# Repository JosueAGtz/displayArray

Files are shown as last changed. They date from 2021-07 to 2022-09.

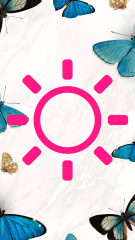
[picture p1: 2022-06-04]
Media/displayArray Plus Themes/ButterflyBig/brightness.png

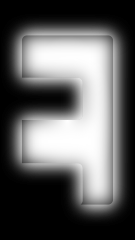
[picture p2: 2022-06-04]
Media/displayArray Plus Themes/StargateBig/am.png

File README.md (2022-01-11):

# Display Array Board
displayArray

The display array is a board that sets 6 ST7735 display with a resolution of 80x160px in a linear array sharing the clock, data, rs, backlight pins together, and leaving individual access to the cs lines of each display, The PCB is intended to be compatible with any Microcontroller or SBC like the Raspberry as it only needs some GPIOs and an SPI Port. This makes the PCB compatible with a simple microcontroller as an Arduino to other more advanced microcontrollers. We could say this board is a breakout board for the arrangement of six displays and 4 buttons. 

The display array has a back connector that allows the comunication with the displays and buttons. The pinout of the connector is the following:

displayArrayPinout

# Display Array Clock Themes ( MY TOP 5 )

displayArrayBINA

displayArrayFlip

displayArray14Seg

displayArrayVFD

displayArrayNixie

# Display Array Clock 

displayArrayClock

# Get the Display Array Board & Controller 

displayArraykofi (https://ko-fi.com/josuealejandrogtz)



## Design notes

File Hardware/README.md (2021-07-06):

# Display Array Hardware

With this files you should be able to modify the board as need, also you can fabricate your own board by using the Gerber files and BOM. 

### Printed Circuit Board
displayArrayPCB

### Schematic
displayArraySCH

### Display Array Board
displayArrayFront
displayArrayBack

# Display Array Controller Hardware

The controller board integrates an ESP32-S2 for its integrated USB Bootloader making it a very compact board with a powerful microcontroller with wifi and Bluetooth capabilities.

This board connects directly to the SPI Display Array Board in its back, it also has an RGB LED and Audio Amplifier for color and audible notifications. The hardware is more than capable to manage 6 displays at a decent frame rate and has enough memory for more than 5 different timezones and clock themes.

This controller has also take into account the possibility of an 8 display board and different display controller detection by the reading of one GPIO, Low logic state for ST7735, and High logic state for ST7789.

### Printed Circuit Board
displayArrayCtrlPCB

### Display Array Controller Board
displayArrayCtrl
displayArrayCtrlMount

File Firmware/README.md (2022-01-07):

## ESP32-S2 Pinout

displayArraySaola

### SPI and Buttons < main.h >
```c++

#define PIN_NUM_RST     33
#define PIN_NUM_DC      34
#define PIN_NUM_MOSI    35
#define PIN_NUM_CLK     36
#define PIN_NUM_BLK     37
#define PIN_NUM_MISO    -1

#define PIN_NUM_CS1     1
#define PIN_NUM_CS2     2
#define PIN_NUM_CS3     3
#define PIN_NUM_CS4     4
#define PIN_NUM_CS5     5
#define PIN_NUM_CS6     6
#define PIN_NUM_CS7     7
#define PIN_NUM_CS8     8

#define PIN_NUM_BTN     0
#define PIN_NUM_BTA     10
#define PIN_NUM_BTB     11
#define PIN_NUM_BTC     12 
#define PIN_NUM_BTD     13

```
## Raspberry Pi Pico Pinout

displayArrayPico

### SPI Port < ST7735.h>

```c++
#define PIN_BLK     21
#define PIN_RST     20
#define PIN_DC      19
#define PIN_SDI     18
#define PIN_SCK     17
#define PIN_CS      16
#define PIN_CS1      16
#define PIN_CS2      15
#define PIN_CS3      14
#define PIN_CS4      13
#define PIN_CS5      12
#define PIN_CS6      11
```

### Buttons < main.h >

```c++
#define PIN_BTNA      6
#define PIN_BTNB      7
#define PIN_BTNC      8
#define PIN_BTND      9
```

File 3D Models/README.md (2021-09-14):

# Display Array 3D Files

### Display Array
displayArray3D

### Controller Board
displayArrayCtrl3D

### USB Board
displayArray3DUSB

### Clock Case
displayArray3D

displayArray3D

### Clock 3D Printed Case
displayArray3DPrint

### Clock Resin 3D Printed Case
displayArray3DPrint
displayArray3DPrint
displayArray3DPrint
displayArray3DPrint

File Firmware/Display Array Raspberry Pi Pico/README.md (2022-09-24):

## Display Array Clock Firmware

For this clock project, I’m using a Raspberry Pi Pico, but the code should be easily ported to any other microcontroller, as the functionality of the clock itself is basic. The Raspberry Pi Pico has a built-in RTC so results easier to implement the clock. Other Microcontrollers with Wifi Capabilities could also obtain the clock data from a web service instead of an intrnal RTC making the board capabilities more atractive as weather or many other kind of IOT notificaions.

displayArrayPico

### SPI Port < ST7735.h>

```c++
#define PIN_BLK     21
#define PIN_RST     20
#define PIN_DC      19
#define PIN_SDI     18
#define PIN_SCK     17
#define PIN_CS      15
#define PIN_CS1      15
#define PIN_CS2      14
#define PIN_CS3      13
#define PIN_CS4      12
#define PIN_CS5      11
#define PIN_CS6      10
```

### Buttons < main.h >

```c++
#define PIN_BTNA      6
#define PIN_BTNB      7
#define PIN_BTNC      8
#define PIN_BTND      9
```

## Posible error in the Pico SDK
There is a chance that your pico-SDK has an error and the program would not start. In your SDK directory: pico-sdk/src/common/pico_time/time.c file comment line 17, //CU_SELECT_DEBUG_PINS(core) and now the program should run with any problem.

```c++
/*
 * Copyright (c) 2020 Raspberry Pi (Trading) Ltd.
 *
 * SPDX-License-Identifier: BSD-3-Clause
 */

#include <limits.h>
#include <stdio.h>
#include <stdlib.h>
#include "pico.h"
#include "pico/time.h"
#include "pico/util/pheap.h"
#include "hardware/sync.h"
#include "hardware/gpio.h"

CU_REGISTER_DEBUG_PINS(core)
//CU_SELECT_DEBUG_PINS(core)

const absolute_time_t ABSOLUTE_TIME_INITIALIZED_VAR(nil_time, 0);
// use LONG_MAX not ULONG_MAX so we don't have sign overflow in time diffs
const absolute_time_t ABSOLUTE_TIME_INITIALIZED_VAR(at_the_end_of_time, ULONG_MAX);

typedef struct alarm_pool_entry {
    absolute_time_t target;
    alarm_callback_t callback;
    void *user_data;
} alarm_pool_entry_t;
```

## Upload your UF2 to your Pico

To upload your code to your pico you just need to connect your pico USB to your computer while holding down the BOOTSEL button on your Pico, this will tell your pico to be mounted as an external drive on your computer where you can just copy paste your UF2 file.

displayArrayPicoUpload

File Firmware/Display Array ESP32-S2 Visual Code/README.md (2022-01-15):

## Visual Studio Code - Espressif Plugin ESP32-S2

The latest firmware includes the addition of 4 timezones with different clock themes with the corresponding country Flag, the firmware is based on the SNTP example provided by Expressif which allows you to configure and set your Wifi’s SSID and password for automatic clock time according to the chosen timezones.

I am very new with the ESP32 so I have tried with MicroPython, CircuitPython, Arduino, and Espressif repository running in Visual Studio Code, and the easiest for me was this last one, so I took the SNTP example located at the protocols example folder. In Visual Studio Code is the Espressif plug-in which makes it very easy and fast to get started with the ESP32.

displayArrayESP32

After installing and opening the example we just need to configure the example for the Wifi credentials and confirm that the partition table is set to 3M.

displayArrayConfig

displayArrayWifi

displayArrayPartition

If you are using the displayArray controller remmber that it does not have a USB to Serial converter so you will need to put it in Boodtloader mode by pressing reset and boot at the same time, then release the reset button and after 3 seconds release also the boot button and your controller will be in bootloader mode.

displayArrayCtlrBootMode

### ESP32-S2 Pinout

displayArraySaola

### SPI and Buttons < main.h >
```c++

#define PIN_NUM_RST     33
#define PIN_NUM_DC      34
#define PIN_NUM_MOSI    35
#define PIN_NUM_CLK     36
#define PIN_NUM_BLK     37
#define PIN_NUM_MISO    -1

#define PIN_NUM_CS1     1
#define PIN_NUM_CS2     2
#define PIN_NUM_CS3     3
#define PIN_NUM_CS4     4
#define PIN_NUM_CS5     5
#define PIN_NUM_CS6     6
#define PIN_NUM_CS7     7
#define PIN_NUM_CS8     8

#define PIN_NUM_BTN     0
#define PIN_NUM_BTA     10
#define PIN_NUM_BTB     11
#define PIN_NUM_BTC     12 
#define PIN_NUM_BTD     13

```

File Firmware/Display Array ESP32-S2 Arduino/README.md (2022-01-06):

# Configuring Arduino IDE for ESP32-S2
displayArray

In order to configure the Arduino IDE for the ESP32-S2 it is necessary to add the Espressif board configuration files.

1.- Open your arduino IDE Preferences and click the add Additional Boards Manager URLs

displayArrayArduinoPreferences

2.- Add the following Espressif Repository for ESP32-S2 URL:
```c++
https://raw.githubusercontent.com/espressif/arduino-esp32/gh-pages/package_esp32_dev_index.json
```
displayArrayArduinoURL

3.- Close and open again the Arduino IDE and click the menu Tools>Board>Boards Manager and search for ESP32 and install the latest version available. 

displayArrayArduinoBoardManager

4.- Now you can select the ESP32S2 Dev Module on the menu Tools>Board>ESP32 Arduino.

displayArrayArduinoBoardModule

For most of the displayArray apps you will need to use the Huge App partition scheme.

displayArrayArduinoBoardPartition

## Steps to install Arduino ESP32 support on Windows ( Alternative )
### Tested on 32 and 64 bit Windows 10 machines

1. Download and install the latest Arduino IDE ```Windows Installer``` from [arduino.cc](https://www.arduino.cc/en/Main/Software)
2. Download and install Git from [git-scm.com](https://git-scm.com/download/win)
3. Start ```Git GUI``` and run through the following steps:
    - Select ```Clone Existing Repository```

        Step 1

    - Select source and destination
        - Sketchbook Directory: Usually ```C:/Users/[YOUR_USER_NAME]/Documents/Arduino``` and is listed underneath the "Sketchbook location" in Arduino preferences.
        - Source Location: ```https://github.com/espressif/arduino-esp32.git```
        - Target Directory: ```[ARDUINO_SKETCHBOOK_DIR]/hardware/espressif/esp32```
        - Click ```Clone``` to start cloning the repository

            Step 2
            Step 3
    - open a `Git Bash` session pointing to ```[ARDUINO_SKETCHBOOK_DIR]/hardware/espressif/esp32``` and execute ```git submodule update --init --recursive``` 
    - Open ```[ARDUINO_SKETCHBOOK_DIR]/hardware/espressif/esp32/tools``` and double-click ```get.exe```

        Step 4

    - When ```get.exe``` finishes, you should see the following files in the directory

        Step 5

4. Plug your ESP32 board and wait for the drivers to install (or install manually any that might be required)
5. Start Arduino IDE
6. Select your board in ```Tools > Board``` menu
7. Select the COM port that the board is attached to
8. Compile and upload (You might need to hold the boot button while uploading)

    Arduino IDE Example

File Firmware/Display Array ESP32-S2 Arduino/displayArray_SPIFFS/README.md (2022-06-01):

# Display Array Clock using 3MB SPIFFS
displayArrayMenu

This code uses the ESP32-S2 Stick internal flash memory for the APP(1MB) and SPIFFS(3MB) making posible just to copy paste your PNG theme files directly to the data folder in your Arduino project and uploaded directly using the SPIFFS Uploader for the ESP32-S2.

In order to use the SPIFFS you should have the SPIFFS tool for ESP32-S2 installed, you can download the tool from: https://github.com/etherfi/arduino-esp32fs-plugin-esp32s2/releases and copy the folder in C:\\Program Files\Arduino\tools like the image below:

displayArray_SPIFFSTOOL

Now that you have installed the SPIFFS Tool you should see in your arduino IDE the option to upload your data to your ESP32-S2.

displayArray_SPIFFSTOOL

The files that you want to upload shoud be contained in a directory data next to your Arduino Sketch, and remember to select the proper partition table for the app and data, in this case 1MB for the APP and 3MB for the data.

displayArray_SPIFFSTOOL

This sketch uses the bb_spi_lcd, PNGdec and NTPClient libraries, so be sure to copy those folders in to your Arduino libraries folder.

displayArrayThemes

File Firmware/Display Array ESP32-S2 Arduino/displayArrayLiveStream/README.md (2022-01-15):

# Display Array Youtube Livestream Notifier Firmware

displayArrayLive

For this Youtube Notifier project, you will need to add some libraries to your Arduino IDE. 

```c++
 Adafruit Neopixel
 Youtube API
 Arduino JSON
 BB SPI LCD
 ```
 
 To add this libraries open your Arduino IDE and click in "Tools>Manage Libraries"

displayArrayYoutube_manageLib

Search and install each library as shown below.

displayArrayYoutube_manageLib_Neopixel

displayArrayYoutube_manageLib_YoutubeAPI

displayArrayYoutube_manageLib_ArduinoJSON

displayArrayYoutube_manageLib_BBSPILCD

After installing all the libraries you should now be able to compile the code, so prepare your ESP32-S2 to load the app, dont forget to use Huge app as partition scheme.

displayArrayYoutube_verified

If you are using the displayArray controller remmber that it does not have a USB to Serial converter so you will need to put it in Boodtloader mode by pressing reset and boot at the same time, then release the reset button and after 3 seconds release also the boot button and your controller will be in bootloader mode. 

displayArrayCtlrBootMode

Now press the upload button to load your app in to your ESP32-S2.

displayArrayYoutube_uploading

For the displayArray controller you will have this message at the end but dont worry your app has been loaded sucessfully and you just need to press the restart button on the controller board. 

displayArrayYoutube_uploadErr

Now its time to configure your desired Youtube Channels IDs and Wifi Credentials

displayArrayYoutube_Settings

displayArrayYoutube_YoutubersImages

The Youtubers Images should be converted and pasted in to the Youtubers.h file, I like to use LCD Image Converter for this.

displayArrayYoutube_YoutubersImagesHEX

## Troubleshooting

You might encounter a little problem with Youtube Livestream Arduino Library as me, this happens because the Youtube page is not always in english and that depends on your location, as I live in Mexico the youtube.com page is always in spanish and that it is why you might need to search for other word rather than "watching".

I have used the word " EN VIVO " -> "{\"text\":\"EN VIVO\"}". to get the livestream in the file YoutubeLiveStream.cpp file.

```c++
bool YouTubeLiveStream::scrapeIsChannelLive(const char *channelId, char *videoIdOut, int videoIdOutSize){
    char command[100];
    sprintf(command, youTubeChannelUrl, channelId);

    bool channelIsLive = true;

    #ifdef YOUTUBE_DEBUG
    Serial.print("url: ");
    Serial.println(command);
    #endif

    int statusCode = makeGetRequest(command, YOUTUBE_HOST, "*/*", YOUTUBE_ACCEPT_COOKIES_COOKIE);
    if(statusCode == 200) {
        if (!client->find("{\"text\":\"EN VIVO\"}"))  
        {
            #ifdef YOUTUBE_DEBUG
            Serial.println(F("Channel doesn't seem to be live"));
            #endif

            channelIsLive = false;
```
You can check what is the better word for you by opening the youtube.com page in an incognito window in your explorer and search in the code source.

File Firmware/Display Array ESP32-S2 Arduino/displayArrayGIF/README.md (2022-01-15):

# Display Array Animated GIF Firmware

displayArrayGIF_Animation

For this Animated GIF project, you will need to add some libraries to your Arduino IDE, this app was written by Larry Bank to test his awesome library capable of showing GIFs. 

```c++
 Animated GIF
 BB SPI LCD
 ```
 
 To add this libraries open your Arduino IDE and click in "Tools>Manage Libraries"

displayArrayGIF_manageLib

Search and install each library as shown below.

displayArrayGIF_manageLib_AnimatedGIF

displayArrayGIF_manageLib_BBSPILCD

After installing all the libraries you should now be able to compile the code, so prepare your ESP32-S2 to load the app, dont forget to use Huge app as partition scheme.

displayArrayGIF_verified

If you are using the displayArray controller remmber that it does not have a USB to Serial converter so you will need to put it in Boodtloader mode by pressing reset and boot at the same time, then release the reset button and after 3 seconds release also the boot button and your controller will be in bootloader mode. 

displayArrayCtlrBootMode

Now press the upload button to load your app in to your ESP32-S2.

displayArrayGIF_uploading

For the displayArray controller you will have this message at the end but dont worry your app has been loaded sucessfully and you just need to press the restart button on the controller board. 

displayArrayGIF_uploadErr

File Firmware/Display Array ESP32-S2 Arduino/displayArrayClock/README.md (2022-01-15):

# Display Array Clock Firmware

displayArrayClock

For this clock project, you will need to add some libraries to your Arduino IDE. 

```c++
 Adafruit Neopixel
 NTP Client
 BB SPI LCD
 ```
 
 To add this libraries open your Arduino IDE and click in "Tools>Manage Libraries"

displayArrayClock_manageLib

Search and install each library as shown below.

displayArrayClock_manageLib_Neopixel

displayArrayClock_manageLib_NTPClient

displayArrayClock_manageLib_BBSPILCD

After installing all the libraries you should now be able to compile the code, so prepare your ESP32-S2 to load the app, dont forget to use Huge app as partition scheme.

displayArrayClock_verified

If you are using the displayArray controller remmber that it does not have a USB to Serial converter so you will need to put it in Boodtloader mode by pressing reset and boot at the same time, then release the reset button and after 3 seconds release also the boot button and your controller will be in bootloader mode. 

displayArrayCtlrBootMode

Now press the upload button to load your app in to your ESP32-S2.

displayArrayClock_uploading

For the displayArray controller you will have this message at the end but dont worry your app has been loaded sucessfully and you just need to press the restart button on the controller board. 

displayArrayClock_uploadErr

Now its time to configure your clock as you prefer by selecting your favorite Clock Theme, your Flag and Timezone, I use the Find and replace option to change all the clock theme definitions and click Replace all.

displayArrayClock_Themerep

Set your Wifi Credentials

displayArrayClock_WifiCredentials

And for the time zone just set it in seconds, for example Mexico is GTM-6 that would be minus 6 hours so that will be -6 * 3600, as there are 3600 seconds in an hour. 

displayArrayClock_timezpnesetting

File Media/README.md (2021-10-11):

# Display Array Board Clock Themes

These are some themes that I have created to be use with the display array board. Every theme can be modified or resized with the Master SVG File for better results. 

### BINA View
displayArrayBINA
### Flip-Flap
displayArrayFlip
### 14 Segments
displayArray14Seg
### VFD
displayArrayVFD
### Nixie Tube
displayArrayNixie
### Pixie PRO
displayArrayPixie
### 7 Segments
displayArray7Seg
### Lixie Cyan
displayArrayLixieBlue
### Lixie Purple
displayArrayLixiePurple
### Matrix
displayArrayMatrix
### NIMO
displayArrayNIMO
### Notebook
displayArrayNotebook
### Wood
displayArrayWood
### Butterfly
displayArrayButterfly
### Flowers
displayArrayFlowers
### RGB
displayArrayRGB
### Predator
displayArrayPredator
### Stargate
displayArrayStargate

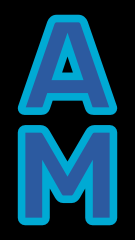
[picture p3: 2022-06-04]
Media/displayArray Plus Themes/SolidBlueBig/am.png

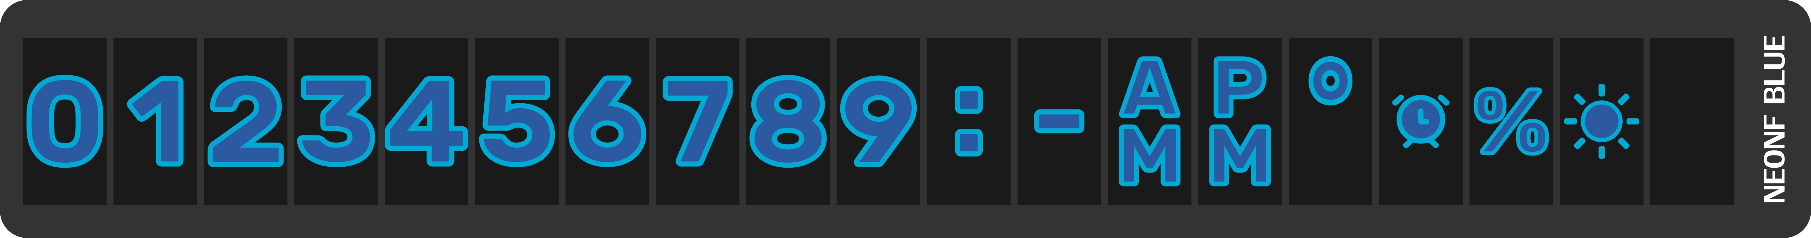
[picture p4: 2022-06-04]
Media/Clock Themes Preview/NeonfBlue.png

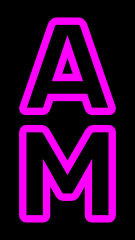
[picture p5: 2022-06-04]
Media/displayArray Plus Themes/NeonPurpleBig/am.png

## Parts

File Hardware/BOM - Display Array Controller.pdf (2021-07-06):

# BOM - SPI Display Array Controller

# | Reference | Part Number | Description | Manufacturer | Distribuitor | Quantity

1 | U1 | ESP32-S2-WROOM | Módulos WiFi (802.11) SMD module, ESP32-S2, 4 MB SPI flash, PCB antenna | Espressif | MOUSER | 1
2 | U2 | NCP187AMT330TAG | LDO Voltage Regulators 1.2A 3.3V Active discharge | On Semiconduxtor | MOUSER | 1
3 | U3 | PAM8301AAF | Audio Amplifiers Audio Amplifiers 1.5W MONO | Diodes Incorporated | MOUSER | 1
4 | S1,S2 | 434123025826 | Tactile Switches WS-TASV SMD 2.5mm 260g 50mA 16V White | WE | MOUSER | 2
5 | J1 | SSW-109-01-S-D | Board to Board & Mezzanine Connectors Tiger Buy Socket Strip with PCB Tails | SAMTEC | MOUSER | 1
6 | C2,C3,C4,C5,C7,C8 | 885012207098 | Multilayer Ceramic Capacitors MLCC - SMD/SMT WCAP-CSGP 0.1uF 0805 10% 50V MLCC | WE | MOUSER | 6
7 | C1,C6 | 885012207103 | Multilayer Ceramic Capacitors MLCC - SMD/SMT WCAP-CSGP 1uF 0805 10% 50V MLCC | WE | MOUSER | 2
8 | R1,R2 | ERJ-6GEYJ103V | Thick Film Resistors 0805 10Kohms 5% AEC-Q200 | Panasonic | MOUSER | 2
9 | D1 | SK6812 | RGB Serial LED | N/A | AliExpress | 1
10 | PCB | S/N | PCB Display Array Controller | N/A | N/A | 1

USB Data and Power Board

1 | J1 | S/N | 12 Pin Generic USBC Connector | N/A | Aliexpress | 1
2 | C1 | 885012207098 | Multilayer Ceramic Capacitors MLCC - SMD/SMT WCAP-CSGP 0.1uF 0805 10% 50V MLCC | WE | MOUSER | 1
3 | C2 | 885012207103 | Multilayer Ceramic Capacitors MLCC - SMD/SMT WCAP-CSGP 1uF 0805 10% 50V MLCC | WE | MOUSER | 1
4 | R1,R2 | ERJ-6GEYJ512V | Thick Film Resistors 0805 5.1Kohms 5% AEC-Q200 | Panasonic | MOUSER | 2
5 | L1 | BLM18KG221SN1D | Ferrite Beads 0603 220ohms 2.2A | Murata | MOUSER | 1
6 | F1 | 0ZCK0075FF2E | Resettable Fuses - PPTC | Bel Fuse | MOUSER | 1
7 | PCB | S/N | PCB USBC Data and Power | N/A | N/A | 1

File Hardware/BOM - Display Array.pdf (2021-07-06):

# BOM - SPI Display Array

# | Reference | Part Number | Description | Manufacturer | Distribuitor | Quantity

1 | Q1 | BSS316NH6327XTSA1 | MOSFET N-Ch 30V 1.4A SOT-23-3 | Infineon | MOUSER | 1
2 | S1,S2,S3,S4 | 434123025826 | Interruptores táctiles WS-TASV SMD 2.5mm 260g 50mA 16V White | WE | MOUSER | 1
3 | J1 | TSM-109-01-F-DH-A | Alojamientos de cables y cabecera .100" Surface Mount Terminal Strip | SAMTEC | MOUSER | 1
4 | C1,C2 | 885012207098 | Capacitores cerámicos (MLCC) - SMD/SMT WCAP-CSGP 0.1uF 0805 10% 50V MLCC | WE | MOUSER | 2
5 | R1,R2,R3,R4,R5 | ERJ-6GEYJ103V | Thick Film Resistors 0805 10Kohms 5% AEC-Q200 | Panasonic | MOUSER | 5
6 | DISPLAY1...6 | LH096NT-IG11G | 160x80 IPS Display Solder 0.96 inch 13 Pin | Limito | AliExpress | 6
7 | PCB | S/N | PCB Display Array | N/A | N/A | 1

Optional

8 | Cable connector | HCSD-09-S-12.00-01-N | IDC Cable 18 Pin | SAMTEC | N/A | 1

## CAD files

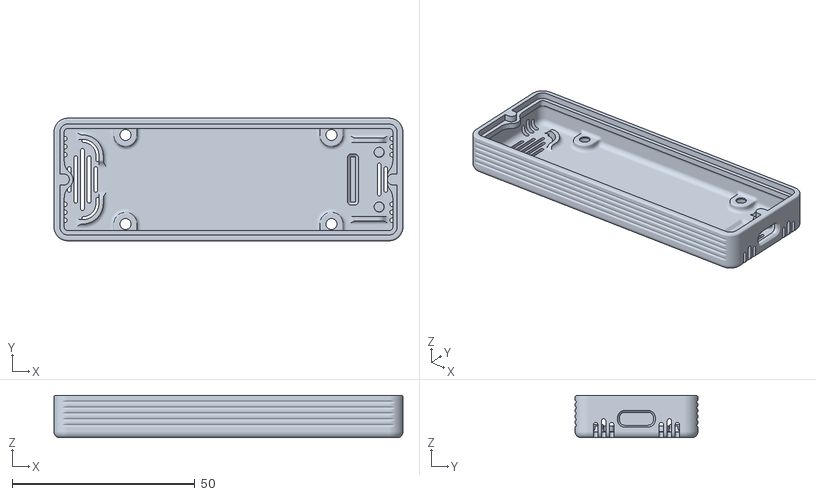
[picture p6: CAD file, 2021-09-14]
3D Models/ResinCase.stl
95.6 x 33.6 x 11.6

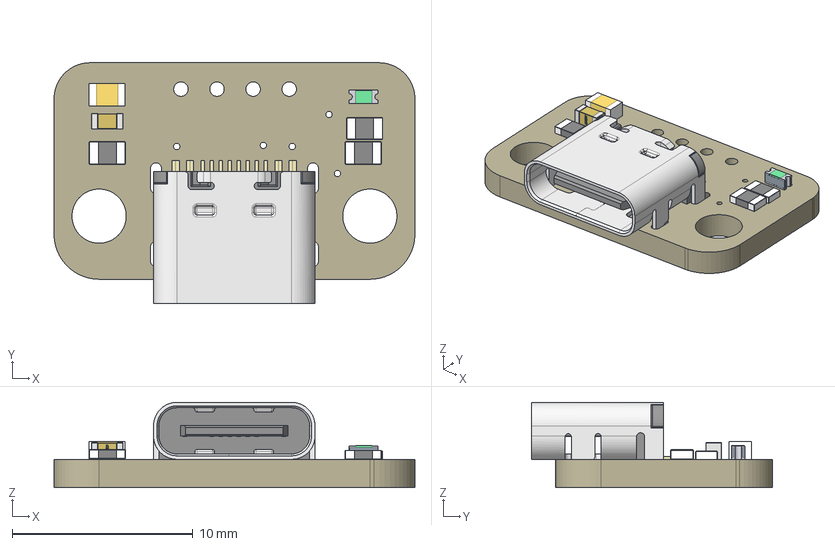
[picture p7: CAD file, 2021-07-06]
3D Models/ClockUSBSTP.step
20.0 x 13.3 x 4.73 mm
Board
C0603
C0603 (1)
core
core (1)
R0603 (2)
Lötende x 2
SE_SMALL_FACESILK
ConPins
PcbPins
Mold
Frame

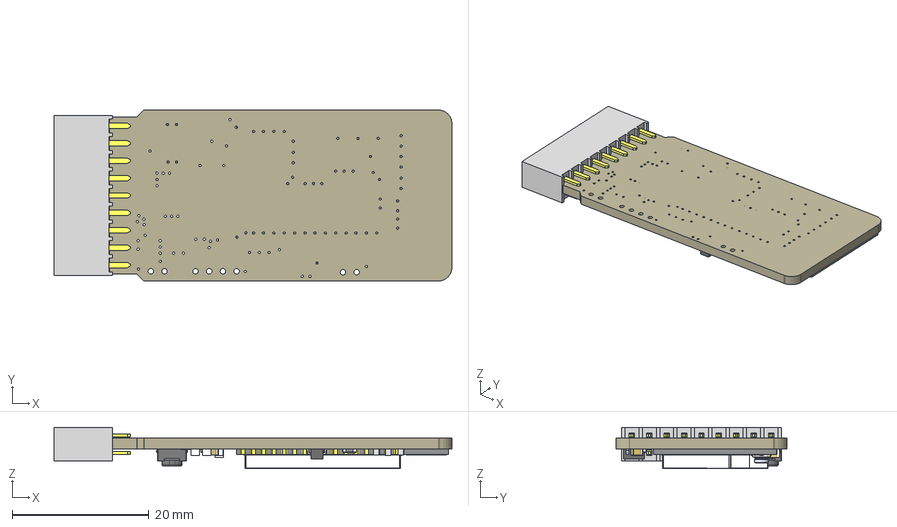
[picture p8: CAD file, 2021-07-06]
3D Models/ClockCtrlSTP.step
58.1 x 25.0 x 6.06 mm
Board
C0603
C0603 (1)
C0603 (2)
C0603 (3)
C0603 (4)
C0603 (5)
C0603 (6)
C0805
core
core (1)
XCVR_ESP32-S2-WROOM
_T1SSW-109-01-T-D
_P2SSW-109-01-T-D
Frame
Cover
Stem
Terminal x 4
Frame (1)
Cover (1)
Stem (1)
Terminal (1) x 4
SOT95P280X145-6N
SE_SMALL_FACESILK
SE_SMALL_SILK
20X20
SON65P250X250X80-7N

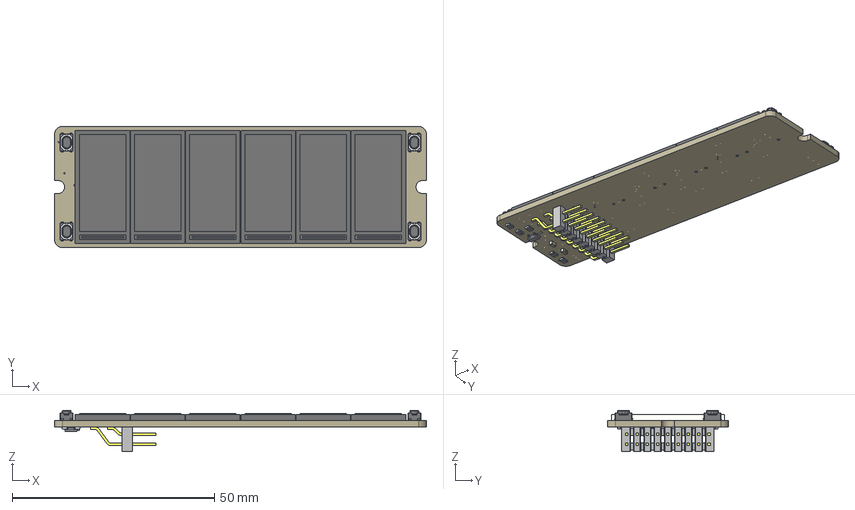
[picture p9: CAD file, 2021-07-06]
3D Models/DisplayArrayBoardSTP.step
92.0 x 30.0 x 10.2 mm
Board
SE_SMALL_SILK
_TSM-109-01-DH_body
_T-1S6-09(-01-9-DH)
C0603
C0603 (1)
core
core (1)
core (2)
core (3)
core (4)
SOT23
Frame
Cover
Stem
Terminal x 4
Frame (1)
Cover (1)
Stem (1)
Terminal (1) x 4
Frame (2)
Cover (2)
Stem (2)
Terminal (2) x 4
Frame (3)
Cover (3)
Stem (3)
Terminal (3) x 4
IPSLCD096_SOLDER
IPSLCD096_SOLDER (1)
IPSLCD096_SOLDER (2)
IPSLCD096_SOLDER (3)
IPSLCD096_SOLDER (4)
IPSLCD096_SOLDER (5)

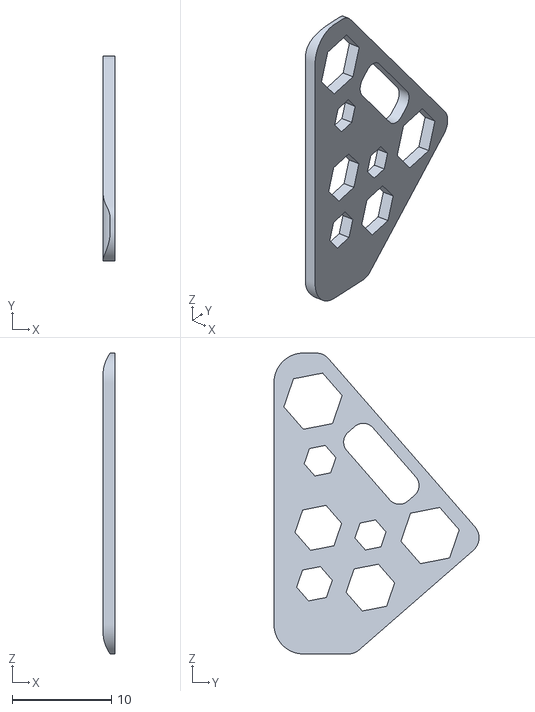
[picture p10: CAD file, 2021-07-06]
3D Models/USBSide.stl
1.20 x 20.7 x 30.4

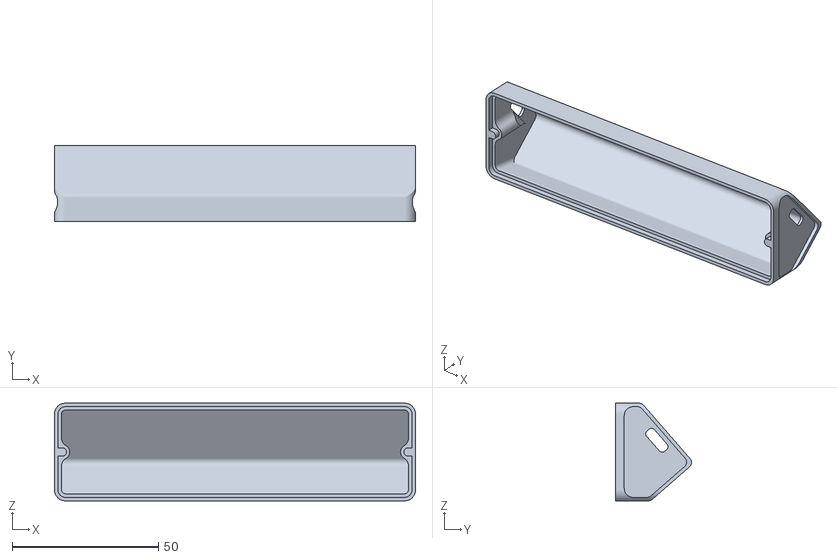
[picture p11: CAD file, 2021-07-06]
3D Models/8DisplayCaseSideUSB.stl
123.4 x 26.0 x 33.4

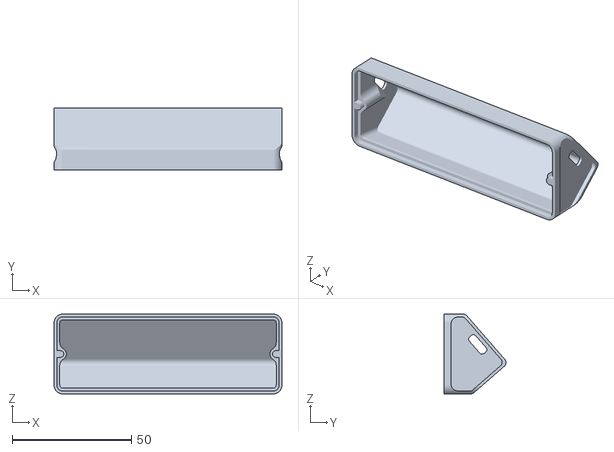
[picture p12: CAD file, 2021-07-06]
3D Models/6DisplayCaseSideUSB.stl
95.4 x 26.0 x 33.4

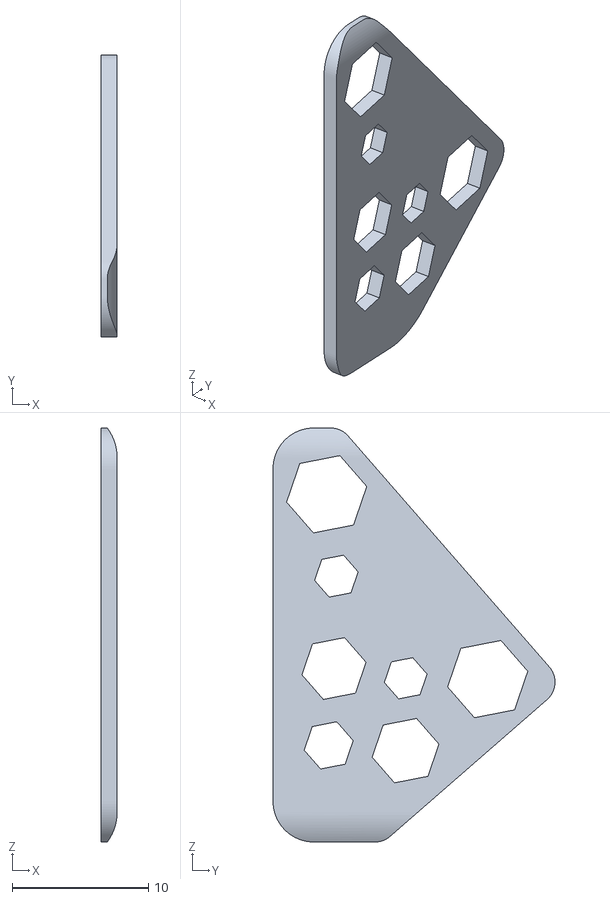
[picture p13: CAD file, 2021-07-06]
3D Models/BlindSide.stl
1.20 x 20.7 x 30.4

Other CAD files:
3D Models/6DisplayCaseBackUSB.stl
3D Models/8DisplayCaseBackUSB.stl

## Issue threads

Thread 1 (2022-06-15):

Crash when running "displayArrayClock"

ewecan, 2022-06-15:
Crashes after running for a few minutes

JosueAGtz, 2022-06-15:
Thanks for taking the time to report this issue, could you please indicate what code are you using or how is it crashing.
I have seen in the past the displayArray Clock app crashing when using the library manager to download or update the bb_spi_lcd, you could try using the included version provided here.

ewecan, 2022-06-17:
Thank you for your reply! Run "displayArrayClock.ino" in the ARDUINO folder, and after a few minutes, switching "space_Pixie" to "slash_Pixie" will get stuck

ewecan, 2022-06-17:
I tried to comment out the following code, the program can run for a long time, but it will still get stuck
 ```
 if((secondsCounter > 25) & (secondsStatus == 0)){
            lcdDrawNumber(2,10);
            //lcdDrawNumber(6,10);
            secondsStatus = 1;
            secondsCounter = 0;
        } else if((secondsCounter > 25) & (secondsStatus == 1)){
            lcdDrawNumber(2,11);
            //lcdDrawNumber(6,11);
            secondsStatus = 0;
            secondsCounter = 0;
        }
```

JosueAGtz, 2022-06-29:
Hi, I have now corrected those errors and the program should run normally, please copy the bb_spi_lcd folder into your Arduino libraries ( replace the existing version with the provided one).

Closed 2022-08-18.

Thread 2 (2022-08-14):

Firmware displayArray_SPIFFS may not work with clock ctrl board

shawnchain, 2022-08-14:
Hi,

Thanks for the great project!

I tested with the latest ClockCtrl eagle file and found the displayArray_SPIFFS may not work on it.
Possible issues include: Pin define mismatch, PWM not working, and SPI LCD write hang.

JosueAGtz, 2022-08-18:
Do you have the Espressif module controller version? I will add the pin definitions for the boards in the README file.

shawnchain, 2022-08-26:
ESP32-S2-4M

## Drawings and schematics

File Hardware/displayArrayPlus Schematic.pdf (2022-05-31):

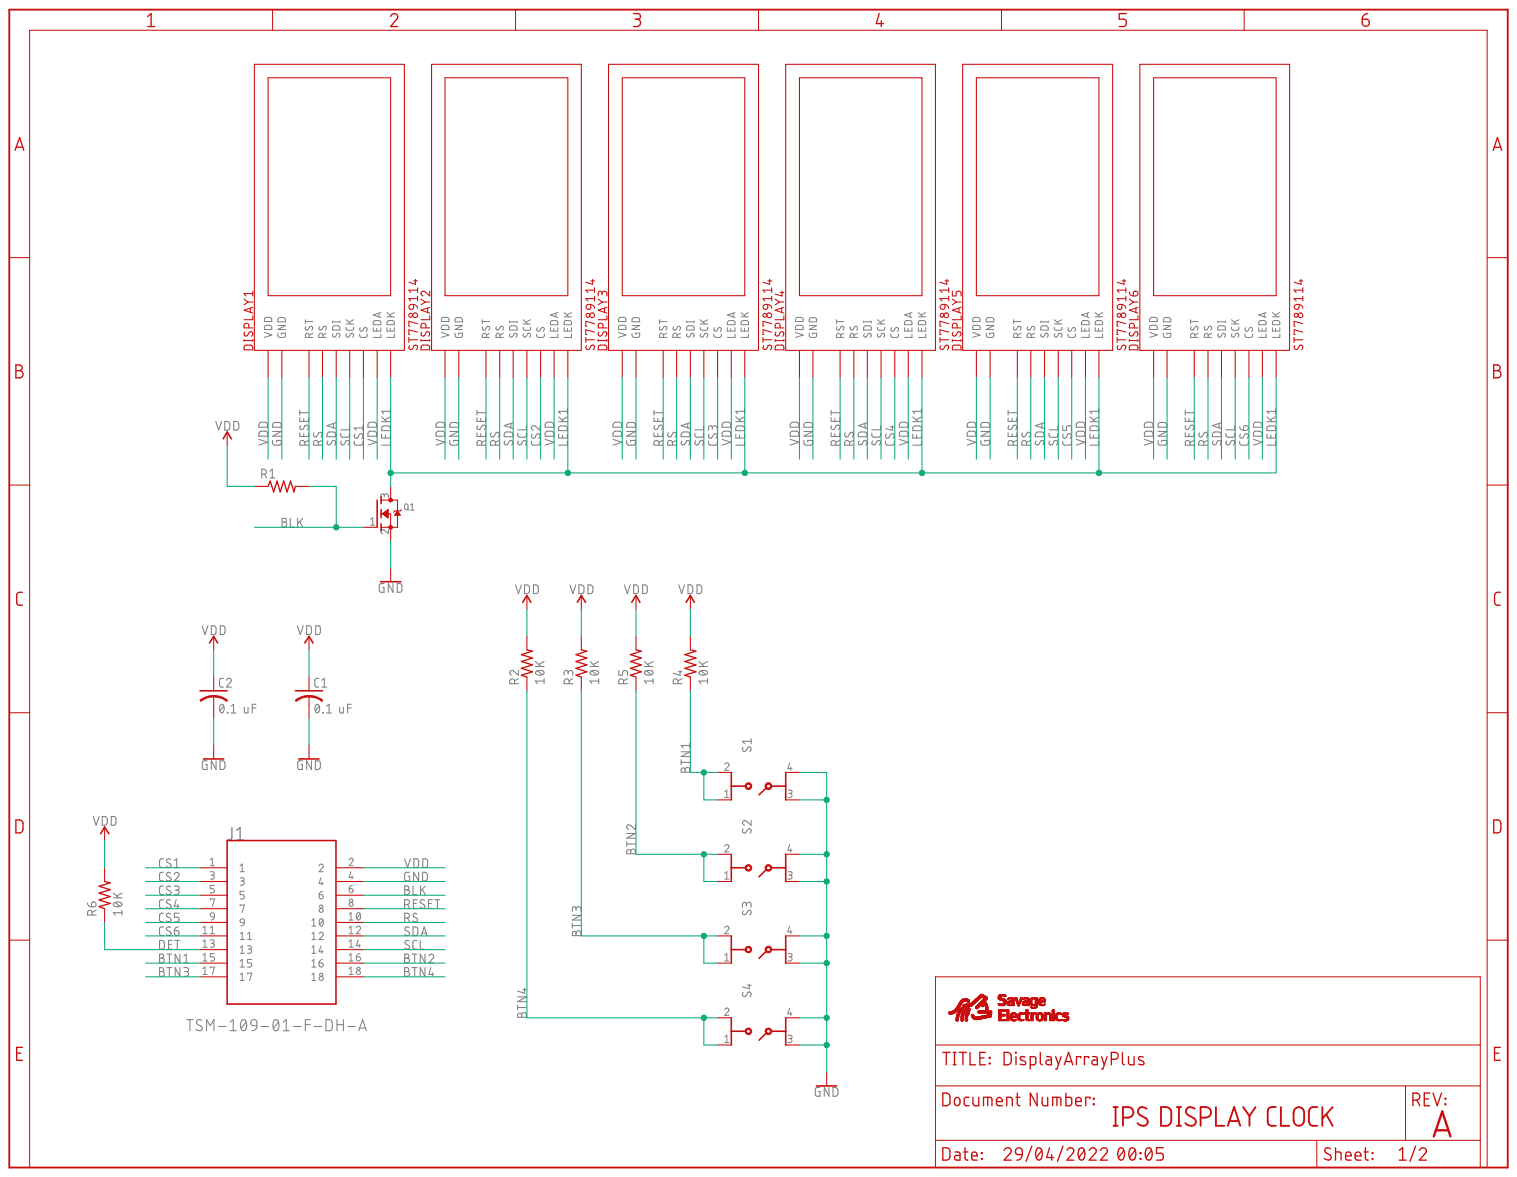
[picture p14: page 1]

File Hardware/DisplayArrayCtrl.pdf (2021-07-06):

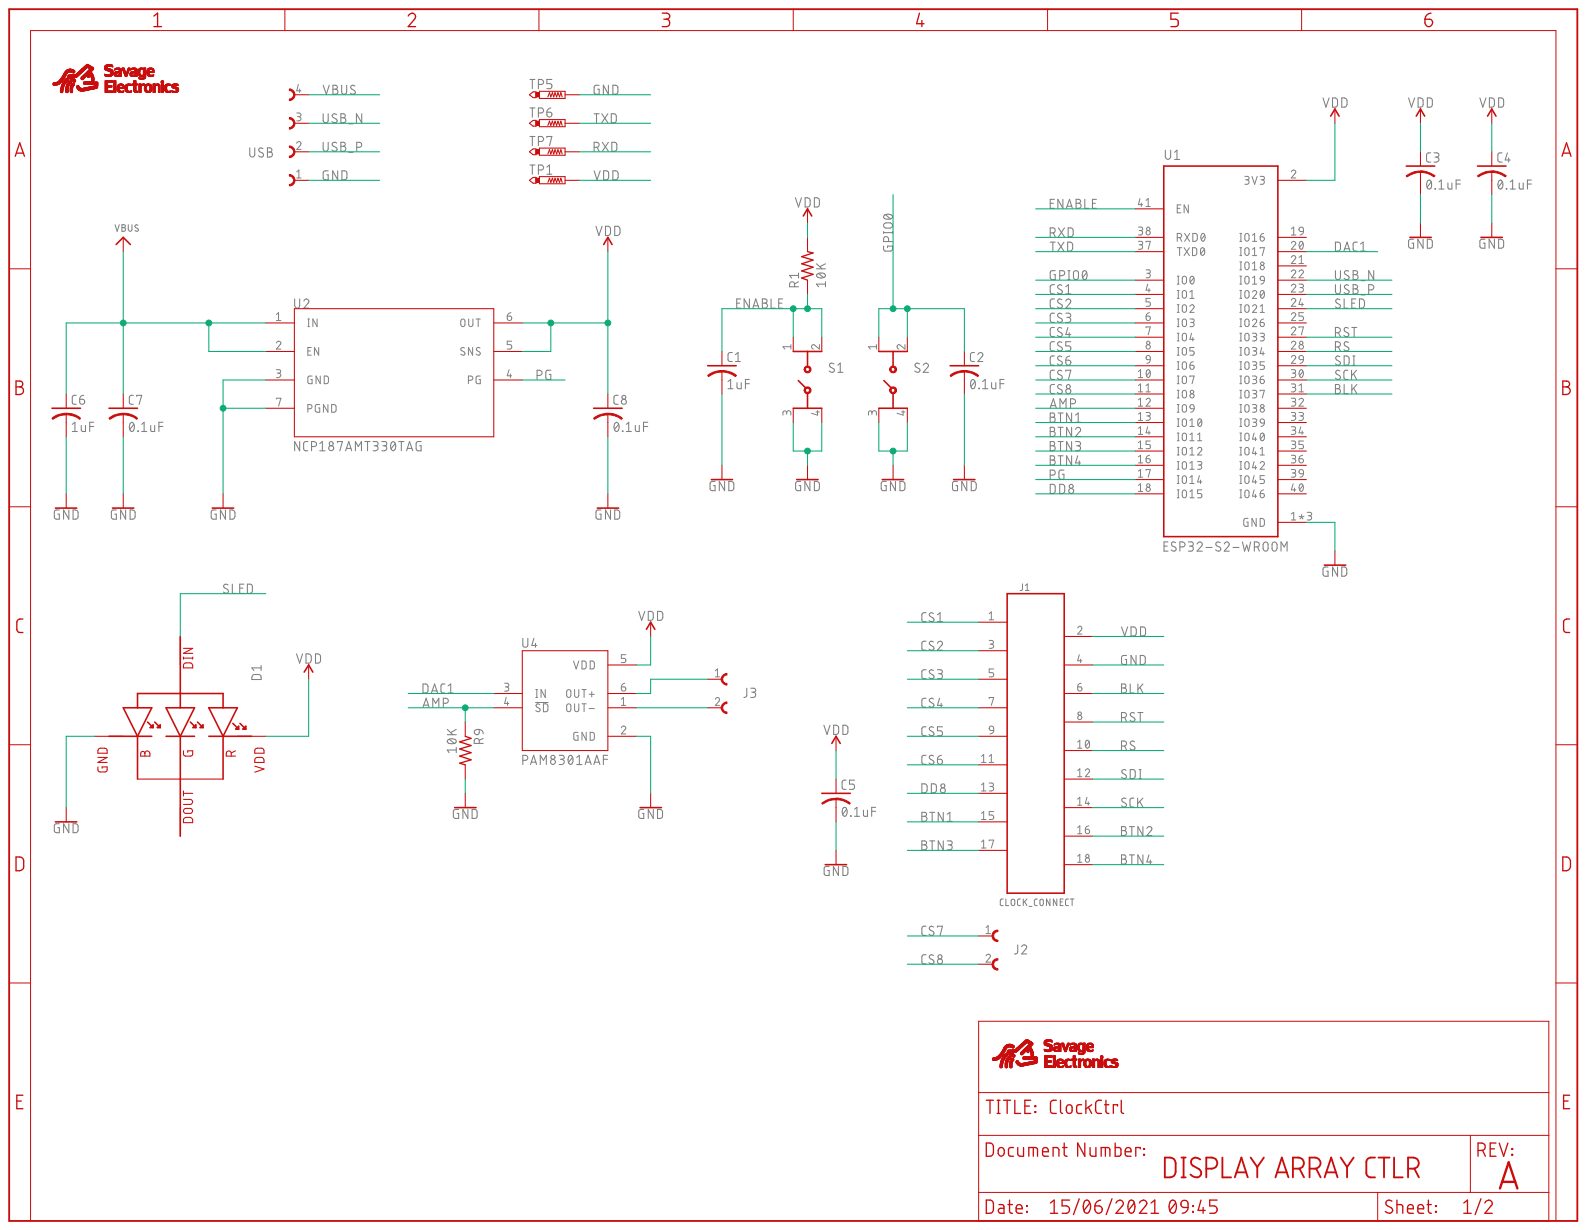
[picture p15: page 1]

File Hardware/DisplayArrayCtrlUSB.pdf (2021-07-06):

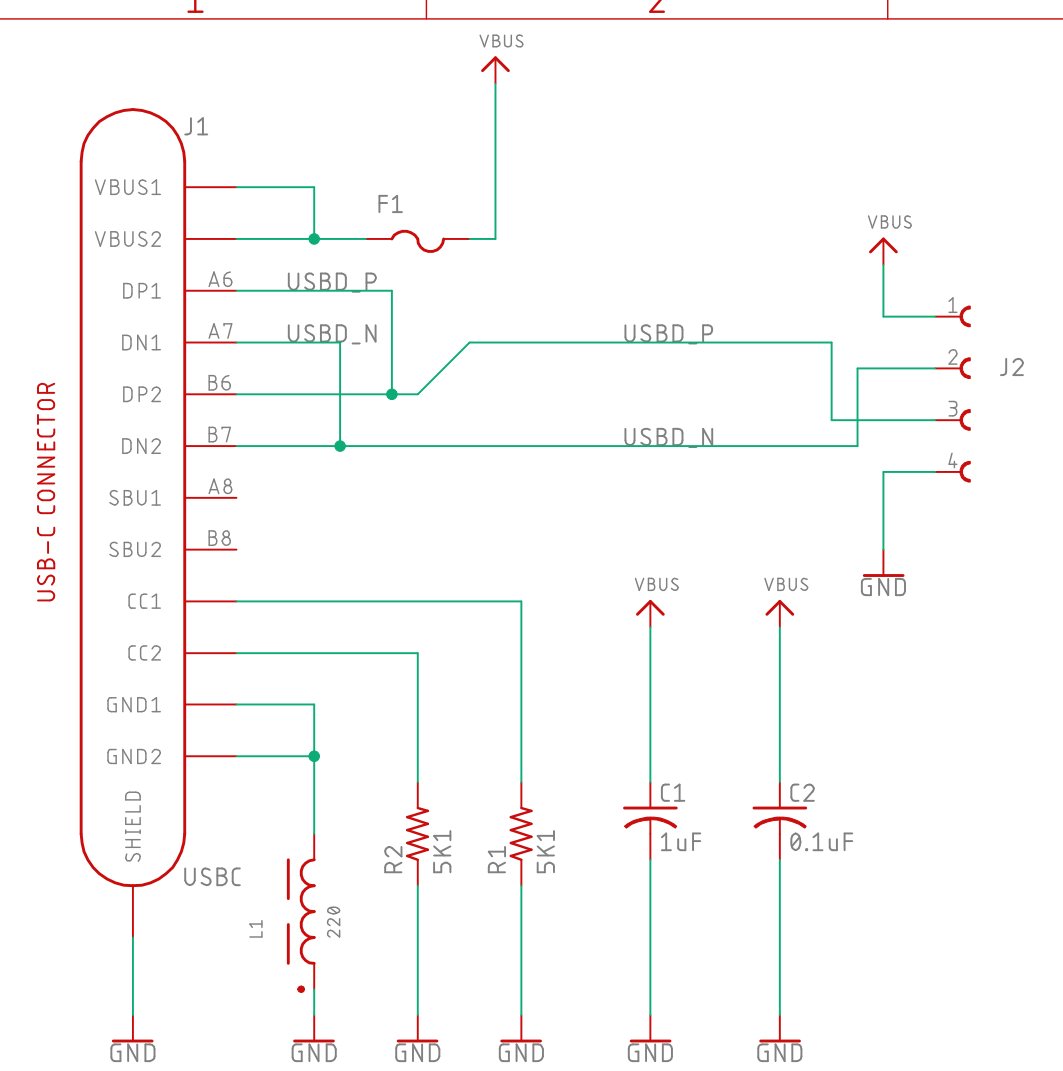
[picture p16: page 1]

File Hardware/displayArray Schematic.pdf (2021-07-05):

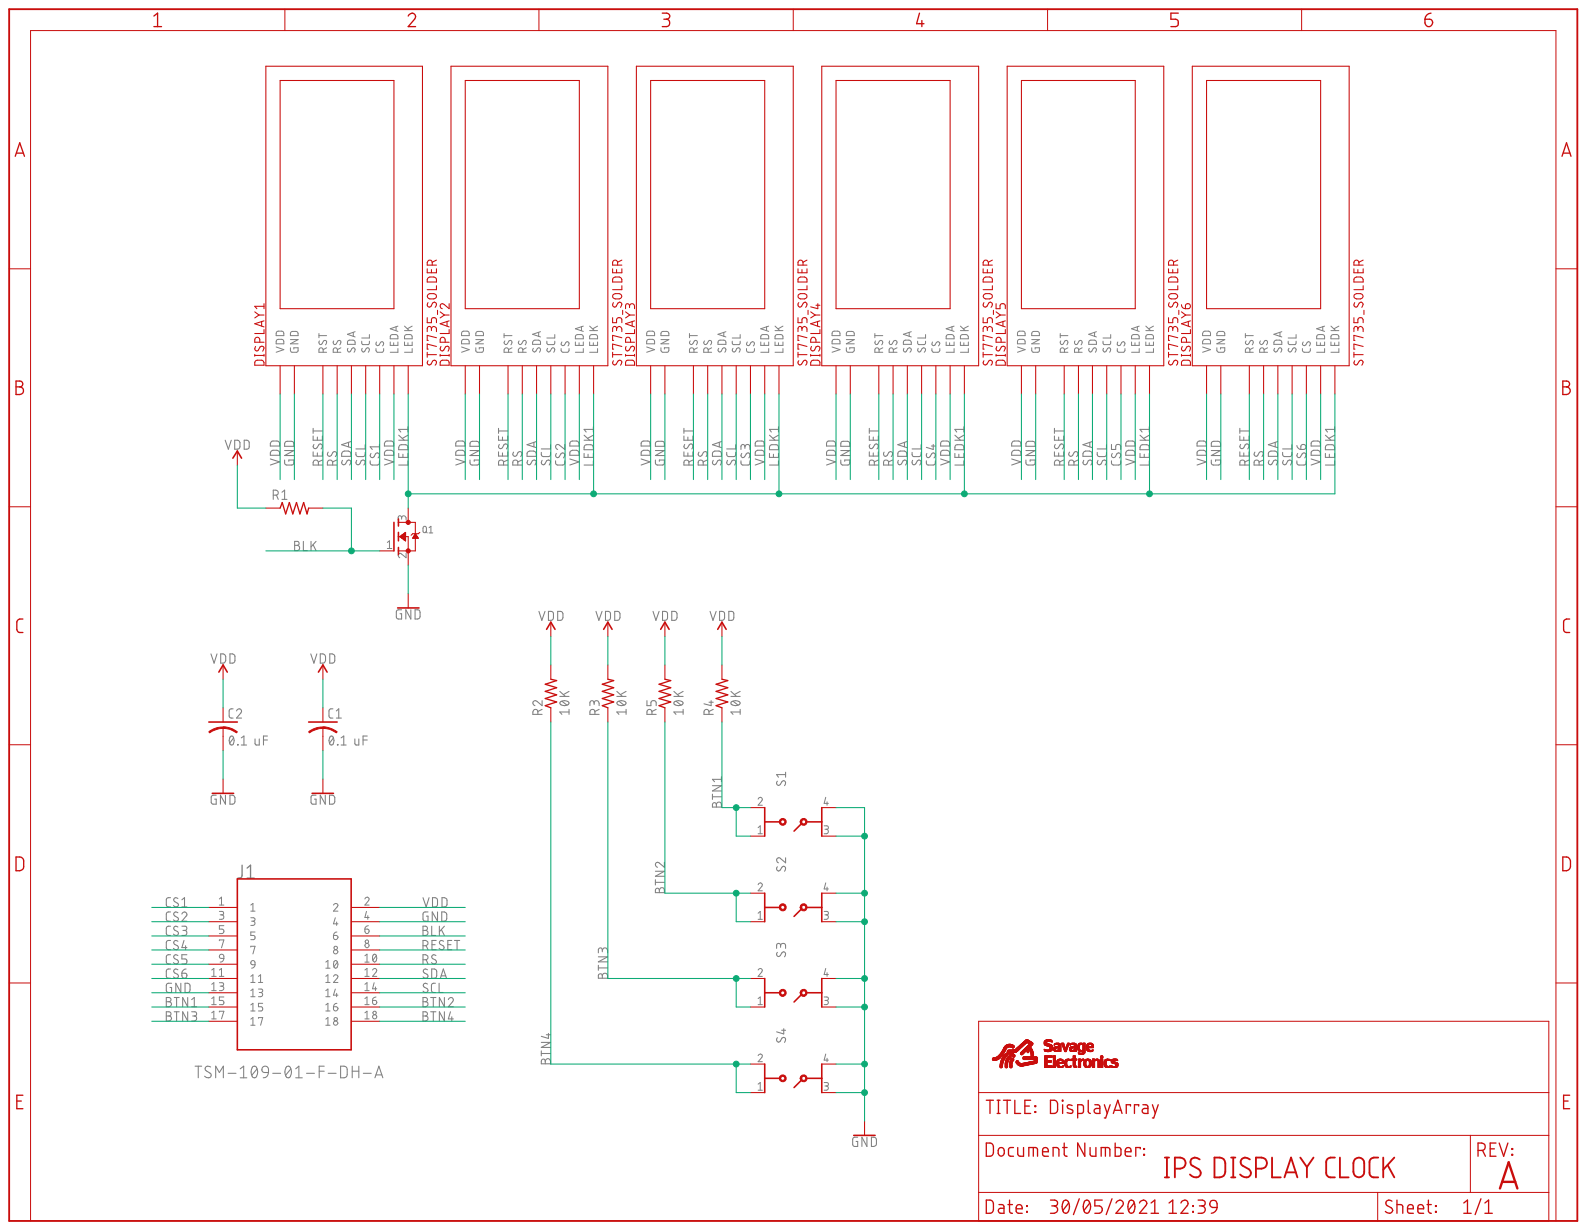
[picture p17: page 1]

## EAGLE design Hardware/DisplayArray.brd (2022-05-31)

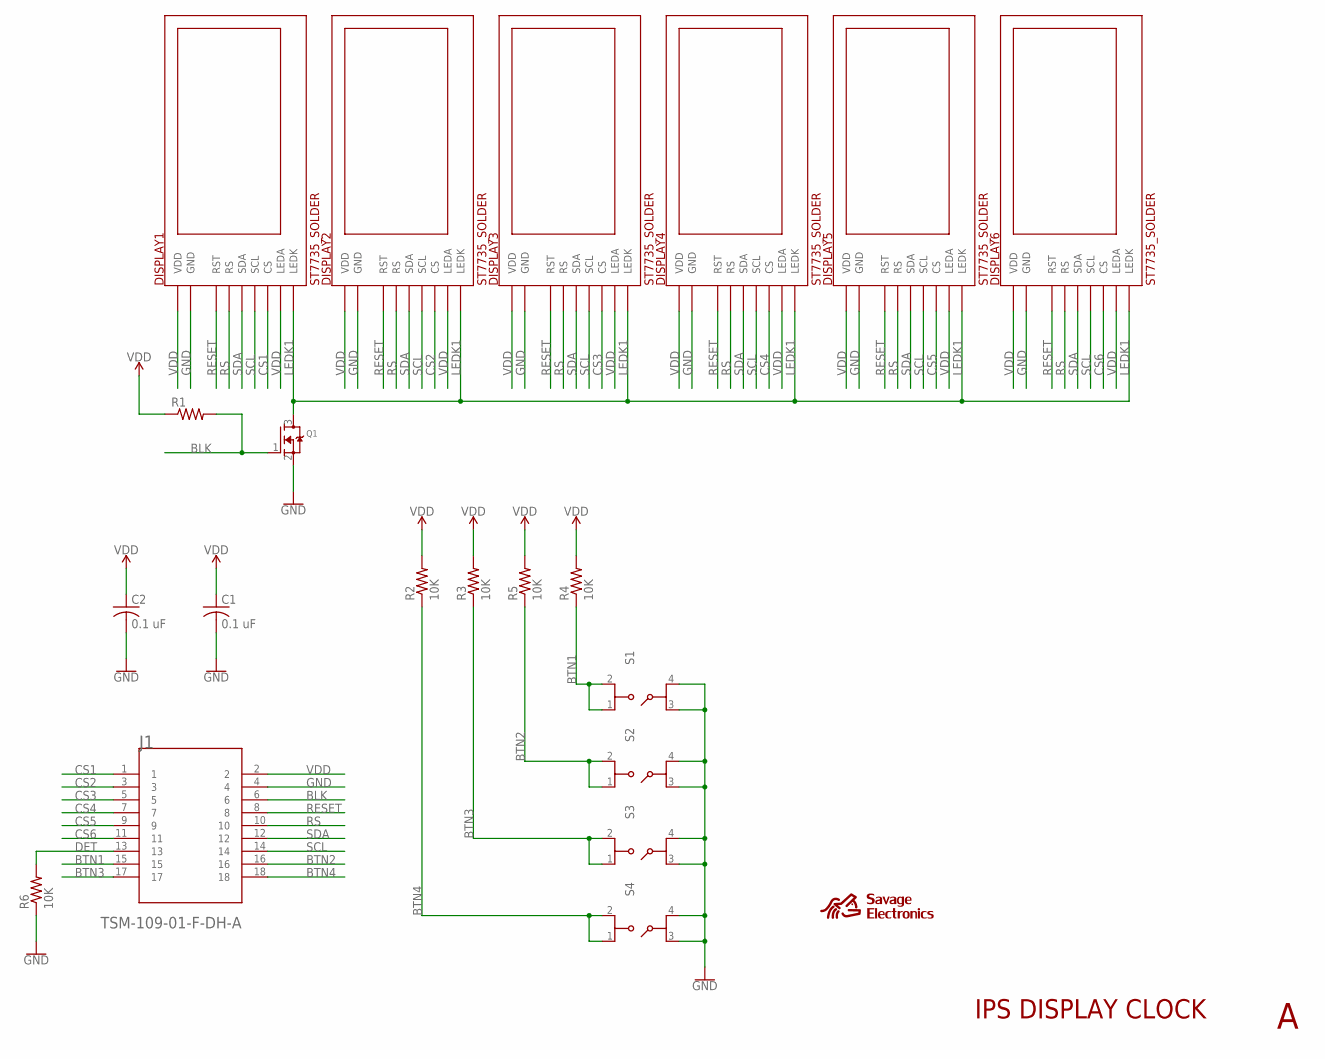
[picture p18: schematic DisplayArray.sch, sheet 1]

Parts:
C1, C2: 0.1 uF; C0603
DISPLAY1, DISPLAY2, DISPLAY3, DISPLAY4, DISPLAY5, DISPLAY6: ST7735_SOLDER; IPSLCD096_SOLDER
J1: TSM-109-01-F-DH-A; SAMTEC-TSM-109-02-X-DH-A
Q1: MOSFET-NREFLOW; SOT23
R1: R-US_R0805; R0805
R2, R3, R4, R5, R6: 10K; R0805
S1, S2, S3, S4: 434123025826
U$3: SE_SMALL_SILK

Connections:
BLK: J1.6, Q1.1 (G), R1.2
BTN1: J1.15, R4.1, S1.1, S1.2
BTN2: J1.16, R5.1, S2.1, S2.2
BTN3: J1.17, R3.1, S3.1, S3.2
BTN4: J1.18, R2.1, S4.1, S4.2
CS1: DISPLAY1.7 (CS), J1.1
CS2: DISPLAY2.7 (CS), J1.3
CS3: DISPLAY3.7 (CS), J1.5
CS4: DISPLAY4.7 (CS), J1.7
CS5: DISPLAY5.7 (CS), J1.9
CS6: DISPLAY6.7 (CS), J1.11
DET: J1.13, R6.2
GND: C1.2, C2.2, DISPLAY1.8 (GND), DISPLAY1.13 (GND), DISPLAY2.8 (GND), DISPLAY2.13 (GND), DISPLAY3.8 (GND), DISPLAY3.13 (GND), DISPLAY4.8 (GND), DISPLAY4.13 (GND), DISPLAY5.8 (GND), DISPLAY5.13 (GND), DISPLAY6.8 (GND), DISPLAY6.13 (GND), J1.4, Q1.2 (S), R6.1, S1.3, S1.4, S2.3, S2.4, S3.3, S3.4, S4.3, S4.4
LEDK1: DISPLAY1.11 (LEDK), DISPLAY2.11 (LEDK), DISPLAY3.11 (LEDK), DISPLAY4.11 (LEDK), DISPLAY5.11 (LEDK), DISPLAY6.11 (LEDK), Q1.3 (D)
RESET: DISPLAY1.6 (RST), DISPLAY2.6 (RST), DISPLAY3.6 (RST), DISPLAY4.6 (RST), DISPLAY5.6 (RST), DISPLAY6.6 (RST), J1.8
RS: DISPLAY1.5 (RS), DISPLAY2.5 (RS), DISPLAY3.5 (RS), DISPLAY4.5 (RS), DISPLAY5.5 (RS), DISPLAY6.5 (RS), J1.10
SCL: DISPLAY1.4 (SCL), DISPLAY2.4 (SCL), DISPLAY3.4 (SCL), DISPLAY4.4 (SCL), DISPLAY5.4 (SCL), DISPLAY6.4 (SCL), J1.14
SDA: DISPLAY1.3 (SDA), DISPLAY2.3 (SDA), DISPLAY3.3 (SDA), DISPLAY4.3 (SDA), DISPLAY5.3 (SDA), DISPLAY6.3 (SDA), J1.12
VDD: C1.1, C2.1, DISPLAY1.10 (VDD), DISPLAY1.12 (LEDA), DISPLAY2.10 (VDD), DISPLAY2.12 (LEDA), DISPLAY3.10 (VDD), DISPLAY3.12 (LEDA), DISPLAY4.10 (VDD), DISPLAY4.12 (LEDA), DISPLAY5.10 (VDD), DISPLAY5.12 (LEDA), DISPLAY6.10 (VDD), DISPLAY6.12 (LEDA), J1.2, R1.1, R2.2, R3.2, R4.2, R5.2

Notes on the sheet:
IPS DISPLAY CLOCK

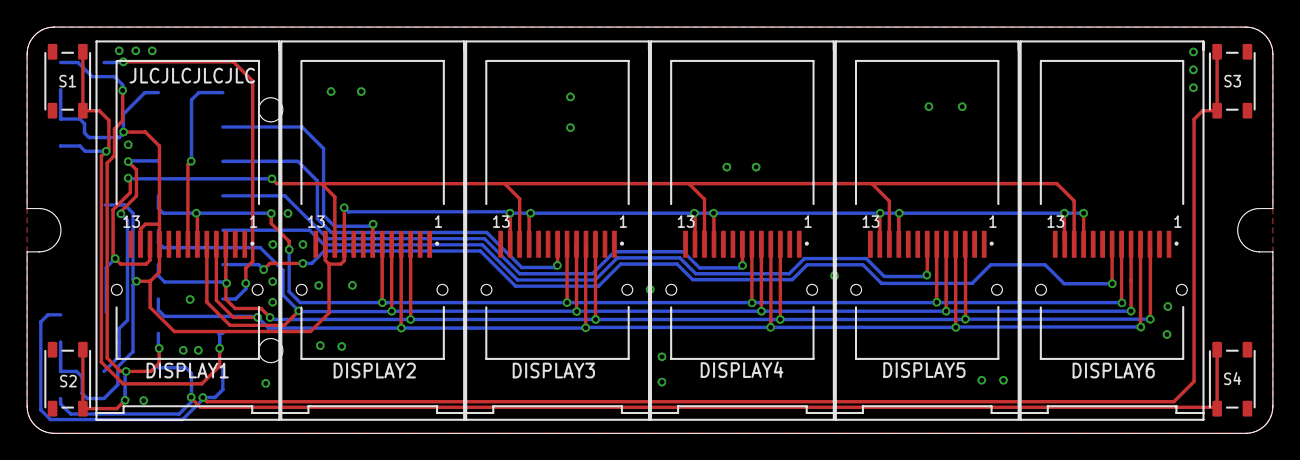
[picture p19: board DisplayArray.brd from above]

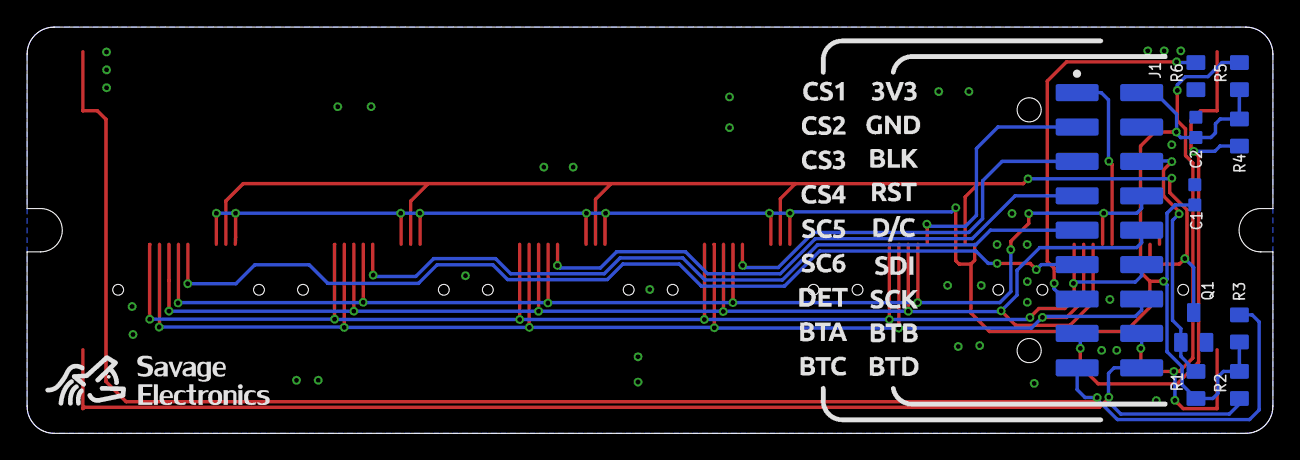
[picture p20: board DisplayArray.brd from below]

Board: 2 copper layers, 92.0 x 30.0 mm, 21 parts (11 on the bottom side), 19 nets.

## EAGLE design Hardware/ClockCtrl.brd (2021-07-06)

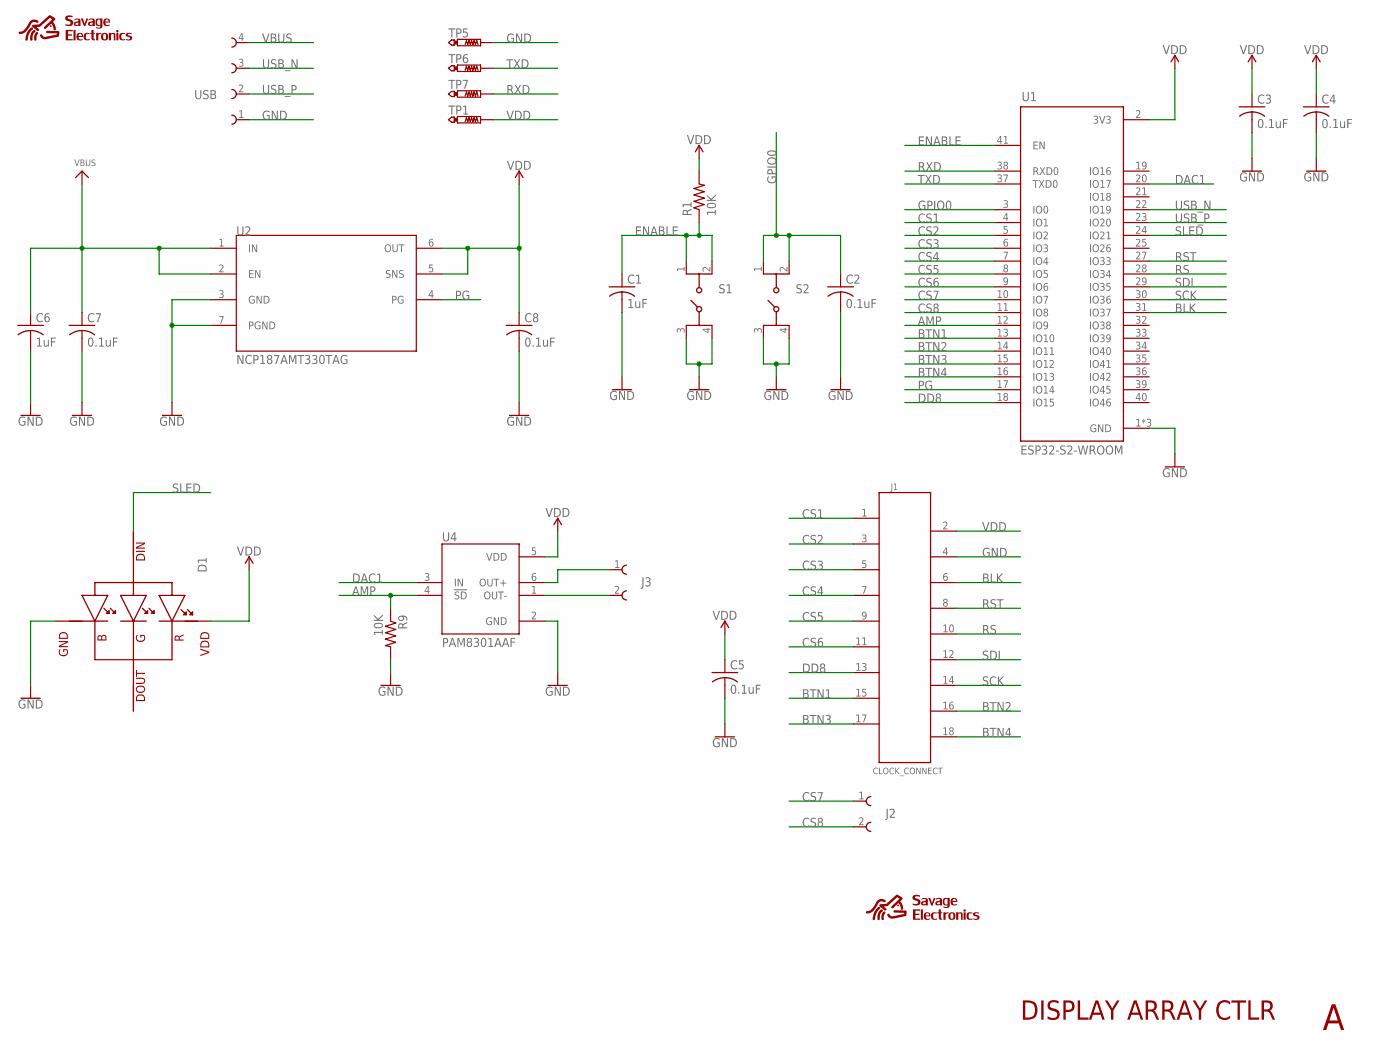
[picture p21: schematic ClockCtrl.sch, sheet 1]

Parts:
C1: 1uF; C0805
C2, C3, C4, C5, C7, C8: 0.1uF; C0603
C6: 1uF; C0603
D1: SK6812; 20X20
J1: CLOCK_CONNECT; CLOCKC_FOOTPRINT
J2, J3: 62000211121
R1, R9: 10K; R0603
S1, S2: 434123025826
TP1, TP5, TP6, TP7: PTR1TP12R; TP12R
U1: ESP32-S2-WROOM; XCVR_ESP32-S2-WROOM
U2: NCP187AMT330TAG; SON65P250X250X80-7N
U4: PAM8301AAF; SOT95P280X145-6N
U$1: SE_SMALL_FSILK; SE_SMALL_FACESILK
U$3: SE_SMALL_SILK
USB: 62000411121

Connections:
AMP: R9.1, U1.12 (IO9), U4.4 (!SD)
BLK: J1.6, U1.31 (IO37)
BTN1: J1.15, U1.13 (IO10)
BTN2: J1.16, U1.14 (IO11)
BTN3: J1.17, U1.15 (IO12)
BTN4: J1.18, U1.16 (IO13)
CS1: J1.1, U1.4 (IO1)
CS2: J1.3, U1.5 (IO2)
CS3: J1.5, U1.6 (IO3)
CS4: J1.7, U1.7 (IO4)
CS5: J1.9, U1.8 (IO5)
CS6: J1.11, U1.9 (IO6)
CS7: J2.1, U1.10 (IO7)
CS8: J2.2, U1.11 (IO8)
DAC1: U1.20 (IO17), U4.3 (IN)
DD8: J1.13, U1.18 (IO15)
ENABLE: C1.1, R1.1, S1.1, S1.2, U1.41 (EN)
GND: C1.2, C2.2, C3.2, C4.2, C5.2, C6.2, C7.2, C8.2, D1.3 (GND), J1.4, R9.2, S1.3, S1.4, S2.3, S2.4, TP5.TP, U1.1 (GND), U1.26 (GND), U1.42 (GND), U2.3 (GND), U2.7 (PGND), U4.2 (GND), USB.1
GPIO0: C2.1, S2.1, S2.2, U1.3 (IO0)
unnamed: J3.2, U4.1 (OUT-)
unnamed: J3.1, U4.6 (OUT+)
PG: U1.17 (IO14), U2.4 (PG)
RS: J1.10, U1.28 (IO34)
RST: J1.8, U1.27 (IO33)
RXD: TP7.TP, U1.38 (RXD0)
SCK: J1.14, U1.30 (IO36)
SDI: J1.12, U1.29 (IO35)
SLED: D1.4 (DIN), U1.24 (IO21)
TXD: TP6.TP, U1.37 (TXD0)
USB_N: U1.22 (IO19), USB.3
USB_P: U1.23 (IO20), USB.2
VBUS: C6.1, C7.1, U2.1 (IN), U2.2 (EN), USB.4
VDD: C3.1, C4.1, C5.1, C8.1, D1.1 (VDD), J1.2, R1.2, TP1.TP, U1.2 (3V3), U2.5 (SNS), U2.6 (OUT), U4.5 (VDD)

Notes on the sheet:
DISPLAY ARRAY CTLR

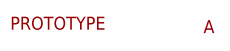
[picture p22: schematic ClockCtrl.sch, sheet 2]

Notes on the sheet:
PROTOTYPE

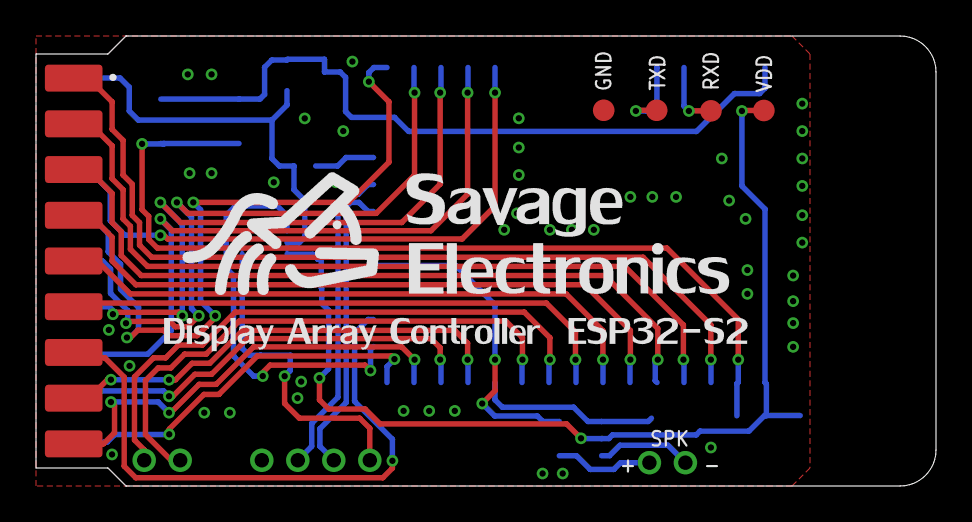
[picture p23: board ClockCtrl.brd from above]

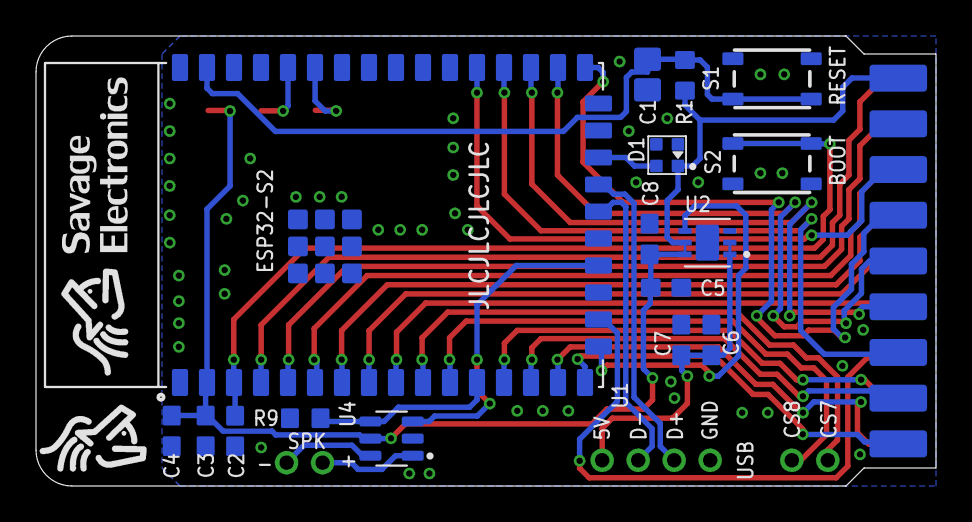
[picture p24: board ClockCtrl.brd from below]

Board: 2 copper layers, 50.0 x 25.0 mm, 26 parts (20 on the bottom side), 33 nets.

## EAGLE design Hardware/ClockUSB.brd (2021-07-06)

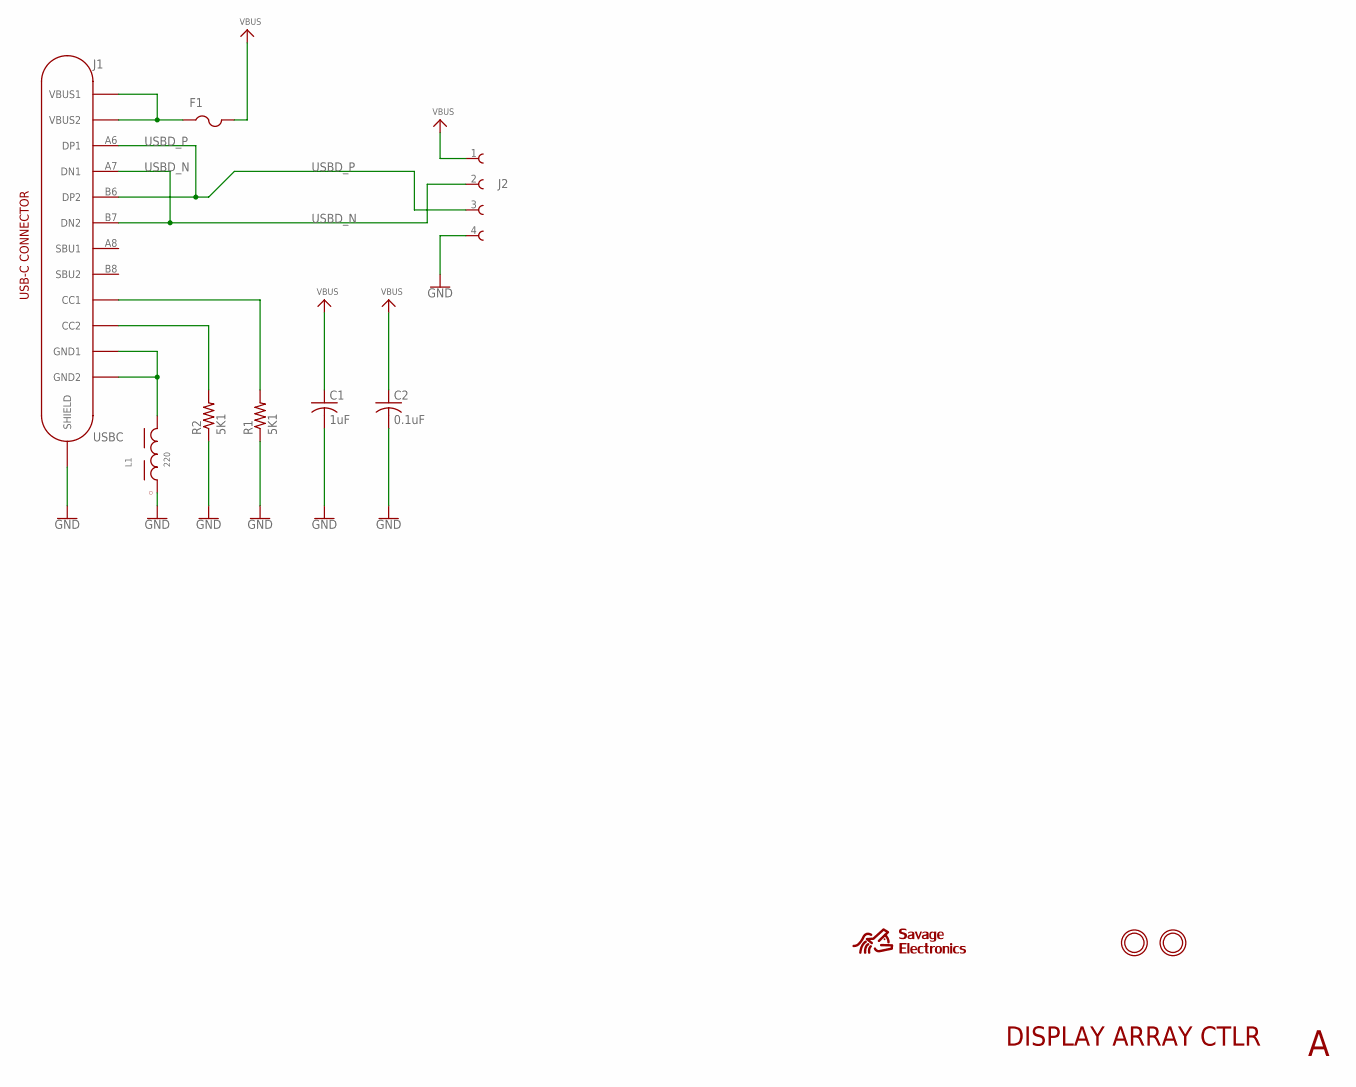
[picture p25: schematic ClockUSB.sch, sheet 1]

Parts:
C1: 1uF; C0603
C2: 0.1uF; C0603
F1: PTCFUSE; R0603
J1: USBC
J2: 62000411121
L1: 220; WE-CBA_0603(W=2.2)
R1, R2: 5K1; R0603
U$3: SE_SMALL_FSILK; SE_SMALL_FACESILK
U$6, U$7: MOUNTINGHOLE3.0THIN; MOUNTINGHOLE_3.0_PLATEDTHIN

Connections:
GND: C1.2, C2.2, J1.S1 (SHIELD), J1.S2 (SHIELD), J1.S3 (SHIELD), J1.S4 (SHIELD), J2.4, L1.1, R1.1, R2.1
unnamed: J1.A1B12 (GND1), J1.B1A12 (GND2), L1.2
unnamed: J1.B5 (CC2), R2.2
unnamed: J1.A5 (CC1), R1.2
unnamed: F1.1, J1.A4B9 (VBUS1), J1.B4A9 (VBUS2)
USBD_N: J1.A7 (DN1), J1.B7 (DN2), J2.2
USBD_P: J1.A6 (DP1), J1.B6 (DP2), J2.3
VBUS: C1.1, C2.1, F1.2, J2.1

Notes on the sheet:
DISPLAY ARRAY CTLR


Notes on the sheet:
PROTOTYPE

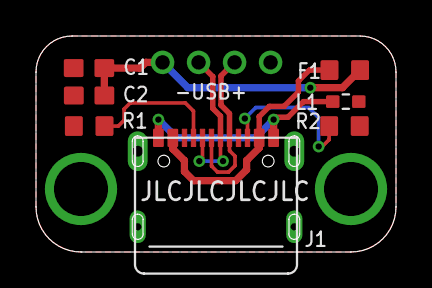
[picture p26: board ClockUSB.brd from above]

Board: 2 copper layers, 20.0 x 12.0 mm, 11 parts (1 on the bottom side), 8 nets.

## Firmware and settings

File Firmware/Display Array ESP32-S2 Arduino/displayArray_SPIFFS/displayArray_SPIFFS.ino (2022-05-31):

#include <Preferences.h>
#include <bb_spi_lcd.h>
#include <PNGdec.h>
#include <string.h>
#include <SPIFFS.h>
//#include <SD.h>

#include <WiFi.h>
#include <WiFiUdp.h>
#include <NTPClient.h>

WiFiUDP ntpUDP;
NTPClient timeClient(ntpUDP);

Preferences preferences;

const char *ssid     = "YourWifi_SSID";
const char *password = "YourPassword";

#define NUM_DISPLAYS       6      // 8 or 6
#define DISPLAY_HEIGHT     80     // 135 or 80  
#define DISPLAY_WIDTH      160    // 240 or 160

#define SYSTEM        0           // system Theme 
#define SYSCLK        1
#define CLKTHEME1     2           // clock Theme 1
#define CLKTHEME2     3           // clock Theme 2

#define CLOCKSCREEN   0
#define MENUSCREEN    1
#define TIMEOSCREEN   2
#define BRTSCREEN     3
#define THMSCREEN     4
#define SETTHMSCREEN  5

#define SYSOK         0
#define SYSERROR      1
#define NOWIFI        2

#define LEFTENTER     3
#define RIGHTBACK     4
#define UPDTTIME      5
#define TIMEOFFS      6
#define SETBRT        7
#define LOADTHM       8
#define UPDTTIMEU     9  
#define TIMEOFFSU     10
#define SETBRTU       11
#define LOADTHMU      12

#define BRTSCROLL     14
#define TIMEOSCROLL   15
#define THMSCROLL     16
#define SAVEBACK      17 
#define MERGEBACK     18
#define SETTHM1       19
#define SETTHM2       20  
#define TIMEUPDATED   21
#define CONNECTNG     22

#define COLON         10
#define DASH          11
#define SPACE         12
#define PERCENT       13
#define AM            14
#define PM            15
#define DEGREES       16
#define ALARM         17
#define BRT           18

#define RST_PIN       7
#define DC_PIN        8
#define TYPEDISP      9
#define ABUTTON       10
#define BBUTTON       11
#define CBUTTON       12
#define DBUTTON       13
#define BLK_PIN       14
#define AMP_PIN       16
#define DAC_PIN       17
#define LED_PIN       18
#define VBAT_PIN      19
#define VUSB_PIN      20
#define CD_PIN        33
#define CS_PIN        34
#define MOSI_PIN      35
#define SCK_PIN       36
#define MISO_PIN      37

#define BLK_CHANNEL        0      // use first channel of 16 channels (started from zero)
#define BLK_TIMER_13_BIT   13     // use 13 bit precission for LEDC timer
#define BLK_BASE_FREQ      36000  // use 36000 Hz as a LEDC base frequency

SPILCD lcd[NUM_DISPLAYS];
PNG png;

String selectedTheme;
char themeAddress[32];
char *themeDirectory[] = {"/clockTheme1/","/clockTheme2/","/clockTheme3/","/clockTheme4/","/clockTheme5/","/clockTheme6/",
                       "/clockTheme7/","/clockTheme8/","/clockTheme9/","/clockTheme10/","/clockTheme11/","/clockTheme12/",
                       "/clockTheme13/","/clockTheme14/"};

uint8_t brightnessTable[] = {1,3,5,10,15,20,30,40,50,60};     // How bright the LED 
uint8_t brightnessPcnt[] = {10,20,30,40,50,60,70,80,90,100};  // How bright the LED is in %
uint8_t brightness = 6;
uint8_t tmpBrightness = 0;

uint8_t tmpClockTheme = 0;
uint8_t clockTheme1 = 8;
uint8_t clockTheme2 = 11;

uint8_t timeOffsetSign;
uint8_t timeOffsetHrs;
int timeOffset = -5;                      // Default timeOffset for Mexico City
int tmpTimeOffset = 0;

unsigned long requestDueTime;             // Time when request due 
uint8_t currentScreen = CLOCKSCREEN;
uint8_t wifiConectionAttmps = 0;
uint8_t currentDisplay = 0;
uint8_t prevMenuSelection = 1;
uint8_t menuSelection = 0;
uint8_t secondStatus = 0;
uint8_t prevHours = 60;
uint8_t prevMinutes = 60;
uint8_t prevSeconds = 60;

// Function to set the backlight brightness with PWM
void setBacklight(uint8_t channel, uint32_t value, uint32_t valueMax = 100) {
  uint32_t duty = (8191 / valueMax) * min(value, valueMax);    // calculate duty, 8191 from 2 ^ 13 - 1
  ledcWrite(channel, duty);                                    // write duty to LEDC
}
// Functions to access a file on the SPIFFS
File myfile;
void * myOpen(const char *filename, int32_t *size) {
  myfile = SPIFFS.open(filename); // SPIFFS
  *size = myfile.size();
  return &myfile;
}
void myClose(void *handle) {
  if (myfile) myfile.close();
}
int32_t myRead(PNGFILE *handle, uint8_t *buffer, int32_t length) {
  if (!myfile) return 0;
  return myfile.read(buffer, length);
}
int32_t mySeek(PNGFILE *handle, int32_t position) {
  if (!myfile) return 0;
  return myfile.seek(position);
}
void PNGDraw(PNGDRAW *pDraw) {    // Function to draw pixels to the display
  unsigned short usPixels[80];
    png.getLineAsRGB565(pDraw, usPixels, PNG_RGB565_BIG_ENDIAN, 0xffffffff);
    spilcdWriteDataBlock(&lcd[currentDisplay], (uint8_t *)usPixels, sizeof(usPixels),  DRAW_TO_LCD | DRAW_WITH_DMA);
}

void drawDisplay(uint8_t display, uint8_t pngImage, uint8_t themeSet) {
  int rc;
  currentDisplay = display - 1;
  if (digitalRead(TYPEDISP))
    spilcdSetPosition(&lcd[currentDisplay], 27, 40, DISPLAY_HEIGHT, DISPLAY_WIDTH, DRAW_TO_LCD);
  else
    spilcdSetPosition(&lcd[currentDisplay], 0, 0, DISPLAY_HEIGHT, DISPLAY_WIDTH, DRAW_TO_LCD);
  switch (pngImage) {
    case 0:
      if(themeSet == SYSTEM)
        rc = png.open("/systemTheme/ok.png", myOpen, myClose, myRead, mySeek, PNGDraw);
      else if(themeSet == SYSCLK)
        rc = png.open("/systemTheme/zero.png", myOpen, myClose, myRead, mySeek, PNGDraw);
      else if (themeSet > SYSCLK){
        if(themeSet == CLKTHEME1)
          selectedTheme = String(themeDirectory[clockTheme1]) + "zero.png";
        else if (themeSet == CLKTHEME2)
          selectedTheme = String(themeDirectory[clockTheme2]) + "zero.png";
        selectedTheme.toCharArray(themeAddress,selectedTheme.length()+1);
        rc = png.open(themeAddress, myOpen, myClose, myRead, mySeek, PNGDraw);
      } 
    break;
    case 1:
      if(themeSet == SYSTEM)
        rc = png.open("/systemTheme/error.png", myOpen, myClose, myRead, mySeek, PNGDraw);
      else if(themeSet == SYSCLK)
        rc = png.open("/systemTheme/one.png", myOpen, myClose, myRead, mySeek, PNGDraw);
      else if (themeSet > SYSCLK){
        if(themeSet == CLKTHEME1)
          selectedTheme = String(themeDirectory[clockTheme1]) + "one.png";
        else if (themeSet == CLKTHEME2)
          selectedTheme = String(themeDirectory[clockTheme2]) + "one.png";
        selectedTheme.toCharArray(themeAddress,selectedTheme.length()+1);
        rc = png.open(themeAddress, myOpen, myClose, myRead, mySeek, PNGDraw);
      } 
    break;
    case 2:
      if(themeSet == SYSTEM)
        rc = png.open("/systemTheme/noWifi.png", myOpen, myClose, myRead, mySeek, PNGDraw);
      else if(themeSet == SYSCLK)
        rc = png.open("/systemTheme/two.png", myOpen, myClose, myRead, mySeek, PNGDraw);
      else if (themeSet > SYSCLK){
        if(themeSet == CLKTHEME1)
          selectedTheme = String(themeDirectory[clockTheme1]) + "two.png";
        else if (themeSet == CLKTHEME2)
          selectedTheme = String(themeDirectory[clockTheme2]) + "two.png";
        selectedTheme.toCharArray(themeAddress,selectedTheme.length()+1);
        rc = png.open(themeAddress, myOpen, myClose, myRead, mySeek, PNGDraw);
      } 
    break;
    case 3:
      if(themeSet == SYSTEM)
        rc = png.open("/systemTheme/leftEnter.png", myOpen, myClose, myRead, mySeek, PNGDraw);
      else if(themeSet == SYSCLK)
        rc = png.open("/systemTheme/three.png", myOpen, myClose, myRead, mySeek, PNGDraw);
      else if (themeSet > SYSCLK){
        if(themeSet == CLKTHEME1)
          selectedTheme = String(themeDirectory[clockTheme1]) + "three.png";
        else if (themeSet == CLKTHEME2)
          selectedTheme = String(themeDirectory[clockTheme2]) + "three.png";
        selectedTheme.toCharArray(themeAddress,selectedTheme.length()+1);
        rc = png.open(themeAddress, myOpen, myClose, myRead, mySeek, PNGDraw);
      } 
    break;
    case 4:
      if(themeSet == SYSTEM)
        rc = png.open("/systemTheme/rightBack.png", myOpen, myClose, myRead, mySeek, PNGDraw);
      else if(themeSet == SYSCLK)
        rc = png.open("/systemTheme/four.png", myOpen, myClose, myRead, mySeek, PNGDraw);
      else if (themeSet > SYSCLK){
        if(themeSet == CLKTHEME1)
          selectedTheme = String(themeDirectory[clockTheme1]) + "four.png";
        else if (themeSet == CLKTHEME2)
          selectedTheme = String(themeDirectory[clockTheme2]) + "four.png";
        selectedTheme.toCharArray(themeAddress,selectedTheme.length()+1);
        rc = png.open(themeAddress, myOpen, myClose, myRead, mySeek, PNGDraw);
      } 
    break;
    case 5:
      if(themeSet == SYSTEM)
        rc = png.open("/systemTheme/updateTime.png", myOpen, myClose, myRead, mySeek, PNGDraw);
      else if(themeSet == SYSCLK)
        rc = png.open("/systemTheme/five.png", myOpen, myClose, myRead, mySeek, PNGDraw);
      else if (themeSet > SYSCLK){
        if(themeSet == CLKTHEME1)
          selectedTheme = String(themeDirectory[clockTheme1]) + "five.png";
        else if (themeSet == CLKTHEME2)
          selectedTheme = String(themeDirectory[clockTheme2]) + "five.png";
        selectedTheme.toCharArray(themeAddress,selectedTheme.length()+1);
        rc = png.open(themeAddress, myOpen, myClose, myRead, mySeek, PNGDraw);
      } 
    break;
    case 6:
      if(themeSet == SYSTEM)
        rc = png.open("/systemTheme/timeOffset.png", myOpen, myClose, myRead, mySeek, PNGDraw);
      else if(themeSet == SYSCLK)
        rc = png.open("/systemTheme/six.png", myOpen, myClose, myRead, mySeek, PNGDraw);
      else if (themeSet > SYSCLK){
        if(themeSet == CLKTHEME1)
          selectedTheme = String(themeDirectory[clockTheme1]) + "six.png";
        else if (themeSet == CLKTHEME2)
          selectedTheme = String(themeDirectory[clockTheme2]) + "six.png";
        selectedTheme.toCharArray(themeAddress,selectedTheme.length()+1);
        rc = png.open(themeAddress, myOpen, myClose, myRead, mySeek, PNGDraw);
      } 
    break;
    case 7:
      if(themeSet == SYSTEM)
        rc = png.open("/systemTheme/setBrt.png", myOpen, myClose, myRead, mySeek, PNGDraw);
      else if(themeSet == SYSCLK)
        rc = png.open("/systemTheme/seven.png", myOpen, myClose, myRead, mySeek, PNGDraw);
      else if (themeSet > SYSCLK){
        if(themeSet == CLKTHEME1)
          selectedTheme = String(themeDirectory[clockTheme1]) + "seven.png";
        else if (themeSet == CLKTHEME2)
          selectedTheme = String(themeDirectory[clockTheme2]) + "seven.png";
        selectedTheme.toCharArray(themeAddress,selectedTheme.length()+1);
        rc = png.open(themeAddress, myOpen, myClose, myRead, mySeek, PNGDraw);
      } 
    break;
    case 8:
      if(themeSet == SYSTEM)
        rc = png.open("/systemTheme/loadTheme.png", myOpen, myClose, myRead, mySeek, PNGDraw);
      else if(themeSet == SYSCLK)
        rc = png.open("/systemTheme/eight.png", myOpen, myClose, myRead, mySeek, PNGDraw);
      else if (themeSet > SYSCLK){
        if(themeSet == CLKTHEME1)
          selectedTheme = String(themeDirectory[clockTheme1]) + "eight.png";
        else if (themeSet == CLKTHEME2)
          selectedTheme = String(themeDirectory[clockTheme2]) + "eight.png";
        selectedTheme.toCharArray(themeAddress,selectedTheme.length()+1);
        rc = png.open(themeAddress, myOpen, myClose, myRead, mySeek, PNGDraw);
      } 
    break;
    case 9:
      if(themeSet == SYSTEM)
        rc = png.open("/systemTheme/updateTimeU.png", myOpen, myClose, myRead, mySeek, PNGDraw);
      else if(themeSet == SYSCLK)
        rc = png.open("/systemTheme/nine.png", myOpen, myClose, myRead, mySeek, PNGDraw);
      else if (themeSet > SYSCLK){
        if(themeSet == CLKTHEME1)
          selectedTheme = String(themeDirectory[clockTheme1]) + "nine.png";
        else if (themeSet == CLKTHEME2)
          selectedTheme = String(themeDirectory[clockTheme2]) + "nine.png";
        selectedTheme.toCharArray(themeAddress,selectedTheme.length()+1);
        rc = png.open(themeAddress, myOpen, myClose, myRead, mySeek, PNGDraw);
      } 
    break;
    case 10:
      if(themeSet == SYSTEM)
        rc = png.open("/systemTheme/timeOffsetU.png", myOpen, myClose, myRead, mySeek, PNGDraw);
      else if(themeSet == SYSCLK)
        rc = png.open("/systemTheme/colon.png", myOpen, myClose, myRead, mySeek, PNGDraw);
      else if (themeSet > SYSCLK){
        if(themeSet == CLKTHEME1)
          selectedTheme = String(themeDirectory[clockTheme1]) + "colon.png";
        else if (themeSet == CLKTHEME2)
          selectedTheme = String(themeDirectory[clockTheme2]) + "colon.png";
        selectedTheme.toCharArray(themeAddress,selectedTheme.length()+1);
        rc = png.open(themeAddress, myOpen, myClose, myRead, mySeek, PNGDraw);
      } 
    break;
    case 11:
      if(themeSet == SYSTEM)
        rc = png.open("/systemTheme/setBrtU.png", myOpen, myClose, myRead, mySeek, PNGDraw);
      else if(themeSet == SYSCLK)
        rc = png.open("/systemTheme/dash.png", myOpen, myClose, myRead, mySeek, PNGDraw);
      else if (themeSet > SYSCLK){
        if(themeSet == CLKTHEME1)
          selectedTheme = String(themeDirectory[clockTheme1]) + "dash.png";
        else if (themeSet == CLKTHEME2)
          selectedTheme = String(themeDirectory[clockTheme2]) + "dash.png";
        selectedTheme.toCharArray(themeAddress,selectedTheme.length()+1);
        rc = png.open(themeAddress, myOpen, myClose, myRead, mySeek, PNGDraw);
      } 
    break;
    case 12:
      if(themeSet == SYSTEM)
        rc = png.open("/systemTheme/loadThemeU.png", myOpen, myClose, myRead, mySeek, PNGDraw);
      else if(themeSet == SYSCLK)
        rc = png.open("/systemTheme/space.png", myOpen, myClose, myRead, mySeek, PNGDraw);
      else if (themeSet > SYSCLK){
        if(themeSet == CLKTHEME1)
          selectedTheme = String(themeDirectory[clockTheme1]) + "space.png";
        else if (themeSet == CLKTHEME2)
          selectedTheme = String(themeDirectory[clockTheme2]) + "space.png";
        selectedTheme.toCharArray(themeAddress,selectedTheme.length()+1);
        rc = png.open(themeAddress, myOpen, myClose, myRead, mySeek, PNGDraw);
      } 
    break;
    case 13:
      if(themeSet == SYSTEM)
        rc = png.open("/systemTheme/percent.png", myOpen, myClose, myRead, mySeek, PNGDraw);
      else if (themeSet > SYSCLK){
        if(themeSet == CLKTHEME1)
          selectedTheme = String(themeDirectory[clockTheme1]) + "percent.png";
        else if (themeSet == CLKTHEME2)
          selectedTheme = String(themeDirectory[clockTheme2]) + "percent.png";
        selectedTheme.toCharArray(themeAddress,selectedTheme.length()+1);
        rc = png.open(themeAddress, myOpen, myClose, myRead, mySeek, PNGDraw);
      } 
    break;
    case 14:
      if(themeSet == SYSTEM)
        rc = png.open("/systemTheme/brtScroll.png", myOpen, myClose, myRead, mySeek, PNGDraw);
      else if (themeSet > SYSCLK){
        if(themeSet == CLKTHEME1)
          selectedTheme = String(themeDirectory[clockTheme1]) + "am.png";
        else if (themeSet == CLKTHEME2)
          selectedTheme = String(themeDirectory[clockTheme2]) + "am.png";
        selectedTheme.toCharArray(themeAddress,selectedTheme.length()+1);
        rc = png.open(themeAddress, myOpen, myClose, myRead, mySeek, PNGDraw);
      } 
    break;
    case 15:
      if(themeSet == SYSTEM)
        rc = png.open("/systemTheme/timeOffScroll.png", myOpen, myClose, myRead, mySeek, PNGDraw);
      else if (themeSet > SYSCLK){
        if(themeSet == CLKTHEME1)
          selectedTheme = String(themeDirectory[clockTheme1]) + "pm.png";
        else if (themeSet == CLKTHEME2)
          selectedTheme = String(themeDirectory[clockTheme2]) + "pm.png";
        selectedTheme.toCharArray(themeAddress,selectedTheme.length()+1);
        rc = png.open(themeAddress, myOpen, myClose, myRead, mySeek, PNGDraw);
      } 
    break;
    case 16:
      if(themeSet == SYSTEM)
        rc = png.open("/systemTheme/themeScroll.png", myOpen, myClose, myRead, mySeek, PNGDraw);
      else if (themeSet > SYSCLK){
        if(themeSet == CLKTHEME1)
          selectedTheme = String(themeDirectory[clockTheme1]) + "degrees.png";
        else if (themeSet == CLKTHEME2)
          selectedTheme = String(themeDirectory[clockTheme2]) + "degrees.png";
        selectedTheme.toCharArray(themeAddress,selectedTheme.length()+1);
        rc = png.open(themeAddress, myOpen, myClose, myRead, mySeek, PNGDraw);
      } 
    break;
    case 17:
      if(themeSet == SYSTEM)
        rc = png.open("/systemTheme/saveBack.png", myOpen, myClose, myRead, mySeek, PNGDraw);
      else if (themeSet > SYSCLK){
        if(themeSet == CLKTHEME1)
          selectedTheme = String(themeDirectory[clockTheme1]) + "alarm.png";
        else if (themeSet == CLKTHEME2)
          selectedTheme = String(themeDirectory[clockTheme2]) + "alarm.png";
        selectedTheme.toCharArray(themeAddress,selectedTheme.length()+1);
        rc = png.open(themeAddress, myOpen, myClose, myRead, mySeek, PNGDraw);
      } 
    break;
    case 18:
      if(themeSet == SYSTEM)
        rc = png.open("/systemTheme/mergeBack.png", myOpen, myClose, myRead, mySeek, PNGDraw);
      else if (themeSet > SYSCLK){
        if(themeSet == CLKTHEME1)
          selectedTheme = String(themeDirectory[clockTheme1]) + "brightness.png";
        else if (themeSet == CLKTHEME2)
          selectedTheme = String(themeDirectory[clockTheme2]) + "brightness.png";
        selectedTheme.toCharArray(themeAddress,selectedTheme.length()+1);
        rc = png.open(themeAddress, myOpen, myClose, myRead, mySeek, PNGDraw);
      } 
    break;
    case 19:
      if(themeSet == SYSTEM)
        rc = png.open("/systemTheme/setTheme1.png", myOpen, myClose, myRead, mySeek, PNGDraw); 
    break;
    case 20:
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
void loop() {

  if (digitalRead(ABUTTON) == LOW){
    if (currentScreen == CLOCKSCREEN){
      currentScreen = MENUSCREEN;
    }else if (currentScreen == MENUSCREEN){
      delay(50); while(digitalRead(ABUTTON) == 0); Serial.println( "Menu selection <- Left! " );
      if (menuSelection == 0)
        menuSelection = 4;  
      menuSelection--;
    }else if (currentScreen == TIMEOSCREEN){
      delay(50); while(digitalRead(ABUTTON) == 0); Serial.println( "UP TimeOffset! " );
      if(tmpTimeOffset < 12)
        tmpTimeOffset++;
      Serial.print( "TimeOffset: " );Serial.println(tmpTimeOffset);
      if (abs(tmpTimeOffset) == 12){
        drawDisplay(3, 1, SYSCLK);
        drawDisplay(4, 2, SYSCLK);
      } else if (abs(tmpTimeOffset) == 11){
        drawDisplay(3, 1, SYSCLK);
        drawDisplay(4, 1, SYSCLK);
      } else if (abs(tmpTimeOffset) == 10){
        drawDisplay(3, 1, SYSCLK);
        drawDisplay(4, 0, SYSCLK);
      }
      if ((tmpTimeOffset < 0) & (tmpTimeOffset > -10)) {
        drawDisplay(2, DASH, SYSCLK);
        drawDisplay(3, 0, SYSCLK);
        drawDisplay(4, abs(tmpTimeOffset), SYSCLK);
      } else if ((tmpTimeOffset >= 0) & (tmpTimeOffset < 10)) {
        drawDisplay(2, SPACE, SYSCLK);
        drawDisplay(3, 0, SYSCLK);
        drawDisplay(4, tmpTimeOffset, SYSCLK);
      } 
    } else if(currentScreen == BRTSCREEN){
      delay(50); while(digitalRead(ABUTTON) == 0); Serial.println( "UP Brightness! " );
        if(tmpBrightness < 9)
          tmpBrightness++;
        if (brightnessPcnt[tmpBrightness] == 100){
        drawDisplay(2, 1,     SYSCLK);
        drawDisplay(3, 0,     SYSCLK);
        drawDisplay(4, 0,     SYSCLK);
      } else if (brightnessPcnt[tmpBrightness] < 100){
        drawDisplay(2, SPACE, SYSCLK);
        drawDisplay(3, tmpBrightness + 1, SYSCLK);
        drawDisplay(4, 0,     SYSCLK);
      }
      setBacklight(BLK_CHANNEL, brightnessTable[tmpBrightness]);
      Serial.print("Brightness at ");Serial.print(brightnessPcnt[brightness]);Serial.println("%");
    } else if(currentScreen == THMSCREEN){
      Serial.print("Clock theme: ");Serial.print(clockTheme1);Serial.println(".");
      clockTheme1++;
      if(clockTheme1 > 13)
        clockTheme1 = 0;
      drawDisplay(2, random(0,9),  CLKTHEME1);
      drawDisplay(3, random(0,9),  CLKTHEME1);
      drawDisplay(4, random(0,9),  CLKTHEME1);
      drawDisplay(5, random(0,9),  CLKTHEME1);
      delay(200);
    } else if(currentScreen == SETTHMSCREEN){
        preferences.putUInt("clockTheme1",clockTheme1);
        prevHours = 60;
        prevMinutes = 60;
        menuSelection = 10;
        currentScreen = CLOCKSCREEN;
    }
  }
  
  if (digitalRead(CBUTTON) == LOW){
    if (currentScreen == CLOCKSCREEN){
      currentScreen = MENUSCREEN;
    }else if (currentScreen == MENUSCREEN){
      delay(50); while(digitalRead(CBUTTON) == 0); Serial.println( "Menu selection -> Right! " );
      menuSelection++;
      if (menuSelection > 3)
        menuSelection = 0;
    }  else if (currentScreen == TIMEOSCREEN){
      delay(50); while(digitalRead(CBUTTON) == 0); Serial.println( "Save TimeOffset! " );
      timeOffset = tmpTimeOffset;
      timeClient.setTimeOffset(3600 * timeOffset);
      drawDisplay(5, SYSOK, SYSTEM);
      preferences.putUInt("timeOffsetHrs",abs(timeOffset));
      if (timeOffset > 0 )
        preferences.putUInt("timeOffsetSign",1);
      else
        preferences.putUInt("timeOffsetSign",0);
      prevHours = 60;
      prevMinutes = 60;
      menuSelection = 10;
      currentScreen = CLOCKSCREEN;
      delay(1000);
    } else if(currentScreen == BRTSCREEN){
      brightness = tmpBrightness;
      setBacklight(BLK_CHANNEL, brightnessTable[brightness]);
      preferences.putUInt("brightness",brightness);
      prevHours = 60;
      prevMinutes = 60;
      menuSelection = 10;
      currentScreen = CLOCKSCREEN;
    } else if(currentScreen == THMSCREEN){
      // Select a theme mode
      drawDisplay(1, SETTHM1, SYSTEM);
      drawDisplay(6, SETTHM2, SYSTEM);
      currentScreen = SETTHMSCREEN;
      delay(250);
      Serial.println("Select where to save the theme.");
    } else if(currentScreen == SETTHMSCREEN){
      clockTheme2 = clockTheme1;
      clockTheme1 = tmpClockTheme;
      preferences.putUInt("clockTheme2",clockTheme2);
      prevHours = 60;
      prevMinutes = 60;
      menuSelection = 10;
      currentScreen = CLOCKSCREEN;
    }
  }
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

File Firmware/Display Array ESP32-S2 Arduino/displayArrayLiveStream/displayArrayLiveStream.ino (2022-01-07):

#include <Adafruit_NeoPixel.h>
#include <WiFi.h>
#include <WiFiClientSecure.h>

#include <YouTubeLiveStream.h>
#include <ArduinoJson.h>
#include <bb_spi_lcd.h>

#include "Youtubers.h"

struct YTChannelDetails
{
  const char *id;
  const char *name;
  bool live;
};

#define NUM_CHANNELS 6

YTChannelDetails channels[NUM_CHANNELS] = {

  {"UCezJOfu7OtqGzd5xrP3q6WA", "Brian Lough", false}, // https://www.youtube.com/channel/UCezJOfu7OtqGzd5xrP3q6WA
  {"UCUW49KGPezggFi0PGyDvcvg", "Zack Freedman", false}, // https://www.youtube.com/channel/UCUW49KGPezggFi0PGyDvcvg
  {"UCu94OHbBYVUXLYPh4NBu10w", "Unexpected Maker", false}, // https://www.youtube.com/channel/UCu94OHbBYVUXLYPh4NBu10w
  {"UCz_G0tNVpnFzwADHkoM5brA", "Dave Darko", false}, // https://www.youtube.com/channel/UCz_G0tNVpnFzwADHkoM5brA
  {"UCp_5PO66faM4dBFbFFBdPSQ", "Bitluni", false}, // https://www.youtube.com/channel/UCp_5PO66faM4dBFbFFBdPSQ
  {"UCv7UOhZ2XuPwm9SN5oJsCjA", "Intermit.Tech", false}, // https://www.youtube.com/channel/UCv7UOhZ2XuPwm9SN5oJsCjA
};

const char *ssid     = "SSID";
const char *password = "Password";

WiFiClientSecure client;
YouTubeLiveStream ytVideo(client, NULL); //"scrapeIsChannelLive" doesn't require a key.

unsigned long delayBetweenRequests = 5000; // Time between requests (5 seconds)
unsigned long requestDueTime;               //time when request due

int channelIndex = 0;
int listChange = false;

#define PINSLED       21

#define CS1_PIN       1
#define CS2_PIN       2
#define CS3_PIN       3
#define CS4_PIN       4
#define CS5_PIN       5
#define CS6_PIN       6

#define RESET_PIN     33
#define DC_PIN        34
#define MOSI_PIN      35
#define SCK_PIN       36
#define BLK_PIN       37
#define MISO_PIN      -1

// ST7735 width
#define DISPLAY_WIDTH 160
#define DISPLAY_HEIGHT 80

// Backlight PWM Control
#define BLK_CHANNEL_0     0     // use first channel of 16 channels (started from zero)
#define BLK_TIMER_13_BIT  13    // use 13 bit precission for BLK timer
#define BLK_BASE_FREQ     5000  // use 5000 Hz as a BLK base frequency

int brightness = 80;    // how bright the Backlight LED is

#define bufferLenght    800
#define buffercounts    32

Adafruit_NeoPixel pixel = Adafruit_NeoPixel(1, PINSLED, NEO_GRB + NEO_KHZ800);

uint8_t imgBuffer[bufferLenght];
SPILCD lcd[6];


// Arduino like analogWrite
// value has to be between 0 and valueMax
void ledcAnalogWrite(uint8_t channel, uint32_t value, uint32_t valueMax = 100) {
  // calculate duty, 8191 from 2 ^ 13 - 1
  uint32_t duty = (8191 / valueMax) * min(value, valueMax);

  // write duty to LEDC
  ledcWrite(channel, duty);
}

void lcdDrawYoutuber(uint8_t Display, uint8_t Youtuber){
  spilcdSetPosition(&lcd[Display],0,0, 80, 160, DRAW_TO_LCD);
  switch(Youtuber){
    case 0:
      for(int k = 0; k < buffercounts; k++){
        for(int j = 0; j < bufferLenght; j++){
          imgBuffer[j] = BrianOff[j+(bufferLenght*k)];
        }
          spilcdWriteDataBlock(&lcd[Display],(uint8_t *)imgBuffer, sizeof(imgBuffer),  DRAW_TO_LCD | DRAW_WITH_DMA);
      }
    break;
    case 6:
      for(int k = 0; k < buffercounts; k++){
        for(int j = 0; j < bufferLenght; j++){
          imgBuffer[j] = BrianLive[j+(bufferLenght*k)];
        }
          spilcdWriteDataBlock(&lcd[Display],(uint8_t *)imgBuffer, sizeof(imgBuffer),  DRAW_TO_LCD | DRAW_WITH_DMA);
      }
    break;
    case 1:
      for(int k = 0; k < buffercounts; k++){
        for(int j = 0; j < bufferLenght; j++){
          imgBuffer[j] = ZackOff[j+(bufferLenght*k)];
        }
          spilcdWriteDataBlock(&lcd[Display],(uint8_t *)imgBuffer, sizeof(imgBuffer),  DRAW_TO_LCD | DRAW_WITH_DMA);
      }
    break;
    case 7:
      for(int k = 0; k < buffercounts; k++){
        for(int j = 0; j < bufferLenght; j++){
          imgBuffer[j] = ZackLive[j+(bufferLenght*k)];
        }
          spilcdWriteDataBlock(&lcd[Display],(uint8_t *)imgBuffer, sizeof(imgBuffer),  DRAW_TO_LCD | DRAW_WITH_DMA);
      }
    break;
    case 2:
      for(int k = 0; k < buffercounts; k++){
        for(int j = 0; j < bufferLenght; j++){
          imgBuffer[j] = UnexpOff[j+(bufferLenght*k)];
        }
          spilcdWriteDataBlock(&lcd[Display],(uint8_t *)imgBuffer, sizeof(imgBuffer),  DRAW_TO_LCD | DRAW_WITH_DMA);
      }
    break;
    case 8:
      for(int k = 0; k < buffercounts; k++){
        for(int j = 0; j < bufferLenght; j++){
          imgBuffer[j] = UnexpLive[j+(bufferLenght*k)];
        }
          spilcdWriteDataBlock(&lcd[Display],(uint8_t *)imgBuffer, sizeof(imgBuffer),  DRAW_TO_LCD | DRAW_WITH_DMA);
      }
    break;
    case 3:
      for(int k = 0; k < buffercounts; k++){
        for(int j = 0; j < bufferLenght; j++){
          imgBuffer[j] = DaveOff[j+(bufferLenght*k)];
        }
          spilcdWriteDataBlock(&lcd[Display],(uint8_t *)imgBuffer, sizeof(imgBuffer),  DRAW_TO_LCD | DRAW_WITH_DMA);
      }
    break;
    case 9:
      for(int k = 0; k < buffercounts; k++){
        for(int j = 0; j < bufferLenght; j++){
          imgBuffer[j] = DaveLive[j+(bufferLenght*k)];
        }
          spilcdWriteDataBlock(&lcd[Display],(uint8_t *)imgBuffer, sizeof(imgBuffer),  DRAW_TO_LCD | DRAW_WITH_DMA);
      }
    break;
    case 4:
      for(int k = 0; k < buffercounts; k++){
        for(int j = 0; j < bufferLenght; j++){
          imgBuffer[j] = BitluniOff[j+(bufferLenght*k)];
        }
          spilcdWriteDataBlock(&lcd[Display],(uint8_t *)imgBuffer, sizeof(imgBuffer),  DRAW_TO_LCD | DRAW_WITH_DMA);
      }
    break;
    case 10:
      for(int k = 0; k < buffercounts; k++){
        for(int j = 0; j < bufferLenght; j++){
          imgBuffer[j] = BitluniLive[j+(bufferLenght*k)];
        }
          spilcdWriteDataBlock(&lcd[Display],(uint8_t *)imgBuffer, sizeof(imgBuffer),  DRAW_TO_LCD | DRAW_WITH_DMA);
      }
    break;
    case 5:
      for(int k = 0; k < buffercounts; k++){
        for(int j = 0; j < bufferLenght; j++){
          imgBuffer[j] = IntermitOff[j+(bufferLenght*k)];
        }
          spilcdWriteDataBlock(&lcd[Display],(uint8_t *)imgBuffer, sizeof(imgBuffer),  DRAW_TO_LCD | DRAW_WITH_DMA);
      }
    break;
    case 11:
      for(int k = 0; k < buffercounts; k++){
        for(int j = 0; j < bufferLenght; j++){
          imgBuffer[j] = IntermitLive[j+(bufferLenght*k)];
        }
          spilcdWriteDataBlock(&lcd[Display],(uint8_t *)imgBuffer, sizeof(imgBuffer),  DRAW_TO_LCD | DRAW_WITH_DMA);
      }
    break;
 }
}
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

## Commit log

2021-07-05 Design Files in Autodesk Eagle
    [DisplayArray.brd, DisplayArray.sch]
2021-07-05 Display Array Schematic - 6 Displays ST7735
2021-07-06 Added Nixie Tube clock theme Inkscape SVG
2021-07-06 Added Display Array Bill of materials

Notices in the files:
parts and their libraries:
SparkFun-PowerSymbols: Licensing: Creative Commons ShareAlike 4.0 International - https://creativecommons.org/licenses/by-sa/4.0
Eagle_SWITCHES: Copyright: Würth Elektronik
